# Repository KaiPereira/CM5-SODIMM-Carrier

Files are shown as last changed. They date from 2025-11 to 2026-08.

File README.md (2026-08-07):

# CM5 SO-DIMM Carrier



This SO-DIMM card essentially let's you turn a CM5 into a NVIDIA Jetson card, turing RK1, and other compatible SO-DIMM standards! It's going to be used for my future server cluster motherboard!
## Custom Features!
- Jetson/Turing RK1/Radxa/etc compatible SO-DIMM connector
- Support for SD Card mounting
- GbE Ethernet
- 1x PCIe Gen 3.0
- 2x USB 3.2 Gen 1 support, 1x USB 2.0
- 1x HDMI 2.0
- 2x 4-Lane MIPI CSI
- Misc buttons/LED's

## PCB Design

The CM5 SO-DIMM carrier is a complex 6-layer PCB, with the stackup HIGH-SPEED/GND/SIGNAL/SIGNAL/GND/HIGH-SPEED, with power running along the top layer! You can easily access the [schematic](https://github.com/KaiPereira/CM5-SODIMM-Carrier/blob/master/PCB_CARRIER/SCHEMATIC.pdf), [PCB layers](https://github.com/KaiPereira/CM5-SODIMM-Carrier/blob/master/PCB_CARRIER/PCB.pdf) and [whole PCB](https://github.com/KaiPereira/CM5-SODIMM-Carrier/blob/master/PCB_CARRIER/PCB_WHOLE.pdf) PDF's!







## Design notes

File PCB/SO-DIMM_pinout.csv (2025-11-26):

Pin Name | Name | Direction
USB3-1-TX_N | USB3-1-TX_N | input
CSI-1_D3_P | CSI-1_D3_P | output
HDMI-0_TX2_P | HDMI-0_TX2_P | input
PCIe_CLKREQ | PCIe_CLKREQ | output
CSI-1_CLK_N | CSI-1_CLK_N | input
USB3-0-TX_N | USB3-0-TX_N | input
PCIe_CLK_N | PCIe_CLK_N | input
USB3-0-TX_P | USB3-0-TX_P | input
HDMI-0_CEC | HDMI-0_CEC | bidirectional
HDMI-0_CLK_P | HDMI-0_CLK_P | input
CSI-1_D1_P | CSI-1_D1_P | output
USB3-0-DM | USB3-0-DM | bidirectional
GBE_MDI3_N | GBE_MDI3_N | bidirectional
MOD_SLEEP | MOD_SLEEP | input
PCIe_RX_P | PCIe_RX_P | output
GBE_MDI0_P | GBE_MDI0_P | bidirectional
PCIe_TX_P | PCIe_TX_P | input
CSI-0_CLK_N | CSI-0_CLK_N | input
USB3-0-DP | USB3-0-DP | bidirectional
CSI-1_D2_P | CSI-1_D2_P | output
USB3-1-DM | USB3-1-DM | bidirectional
CSI-1_D0_N | CSI-1_D0_N | output
CSI-0_D2_P | CSI-0_D2_P | output
USB3-1-DP | USB3-1-DP | bidirectional
CSI-0_D0_N | CSI-0_D0_N | output
PCIe_nRST | PCIe_nRST | input
CSI-1_D1_N | CSI-1_D1_N | output
USB_P | USB_P | bidirectional
HDMI-0_TX1_N | HDMI-0_TX1_N | input
POWER_BMC | POWER_BMC | output
USB3-1-RX_P | USB3-1-RX_P | output
CSI-0_D3_P | CSI-0_D3_P | output
CSI-0_SDA | CSI-0_SDA | bidirectional
I2C-0_SCL | I2C-0_SCL | bidirectional
HDMI-0_SDA | HDMI-0_SDA | bidirectional
PCIe_TX_N | PCIe_TX_N | input
CSI-1_CLK_P | CSI-1_CLK_P | input
SHUT_REQ_BMC | SHUT_REQ_BMC | input
HDMI-0_TX0_P | HDMI-0_TX0_P | input
GBE_LED_LINK | GBE_LED_LINK | bidirectional
USB3-1-TX_P | USB3-1-TX_P | input
GBE_LED_ACT | GBE_LED_ACT | bidirectional
PCIe_CLK_P | PCIe_CLK_P | input
HDMI-0_TX2_N | HDMI-0_TX2_N | input
USB3-0-RX_P | USB3-0-RX_P | output
GBE_MDI3_P | GBE_MDI3_P | bidirectional
USB3-1-RX_N | USB3-1-RX_N | output
CSI-0_CLK_P | CSI-0_CLK_P | input
HDMI-0_TX1_P | HDMI-0_TX1_P | input
CSI-0_PWDN | CSI-0_PWDN | output
HDMI-0_SCL | HDMI-0_SCL | bidirectional
CSI-0_D2_N | CSI-0_D2_N | output
USB_N | USB_N | bidirectional
RESET_BMC | RESET_BMC | bidirectional
PCIe_RX_N | PCIe_RX_N | output
GBE_MDI2_N | GBE_MDI2_N | bidirectional
SLEEP/WAKE | SLEEP/WAKE | bidirectional
HDMI-0_TX0_N | HDMI-0_TX0_N | input
USB3-0-RX_N | USB3-0-RX_N | output
CSI-0_D1_P | CSI-0_D1_P | output
CSI-1_PWDN | CSI-1_PWDN | output
CSI-0_D1_N | CSI-0_D1_N | output
GBE_MDI1_N | GBE_MDI1_N | bidirectional
GBE_MDI1_P | GBE_MDI1_P | bidirectional
CSI-0_SCL | CSI-0_SCL | bidirectional
CSI-0_D3_N | CSI-0_D3_N | output
CSI-1_D3_N | CSI-1_D3_N | output
GBE_MDI2_P | GBE_MDI2_P | bidirectional
CSI-1_D0_P | CSI-1_D0_P | output
I2C-0_SDA | I2C-0_SDA | bidirectional
CSI-0_D0_P | CSI-0_D0_P | output
GBE_MDI0_N | GBE_MDI0_N | bidirectional
CSI-1_D2_N | CSI-1_D2_N | output
HDMI-0_HPD | HDMI-0_HPD | input
HDMI-0_CLK_N | HDMI-0_CLK_N | input

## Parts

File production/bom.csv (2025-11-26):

Designator | Footprint | Quantity | Value | LCSC Part #
C1, C10, C14, C15, C17, C19, C2, C3, C4, C5, C6 | 0402 | 11 | 0.1uF
C11, C20 | 0603 | 2 | 10uF
C12, C13, C16, C18, C7, C8, C9 | 0402 | 7 | 1uF
D1 | 0805 | 1 | Green
D2 | 0805 | 1 | Yellow
J1 | SODIMM_DDR4_EDGE | 1 | SODIMM-260_Split
J2 | microSD_HC_Hirose_DM3AT-SF-PEJM5 | 1 | Micro_SD_Card_Det2
MODULE1 | Raspberry-Pi-4-Compute-Module-B | 1 | 10164227-1004A1RLF | 2x DF40C-100DS-0.4V
MODULE2 | Raspberry-Pi-4-Compute-Module-A | 1 | 10164227-1004A1RLF | 2x DF40C-100DS-0.4V
Q2, Q3, Q5 | SOT-23-3 | 3 | BSS138
Q4 | SOT-323_SC-70 | 1 | BC817-40
R1, R15 | 0402 | 2 | 330
R10, R11, R12, R13, R16, R17, R18, R19, R2, R20, R21, R24, R25, R5, R6, R7, R8, R9 | 0402 | 18 | 10K
R14 | 0402 | 1 | 12K
R22, R23, R26, R27, R28, R29, R3, R30, R31, R32, R33, R34, R35, R36, R37, R38, R39, R4, R40, R41, R42, R43, R44, R45, R46, R47, R48, R49, R50, R51, R52, R53, R54, R55, R56, R57, R58, R59, R60, R61 | 0402 | 40 | 0
SW1 | SW_DIP_SPSTx04_Slide_Copal_CHS-04B_W7.62mm_P1.27mm | 1 | SW_DIP_x04
TP1 | TestPoint_Pad_D1.0mm | 1 | RTC Test
TP2 | TestPoint_Pad_D1.0mm | 1 | Sleep Status Output
U1, U2, U3 | TSSOP-24_4.4x5mm_P0.4mm | 3 | SN74LVC8T245
U4 | TSOT-23-5 | 1 | RT9742GGJ5

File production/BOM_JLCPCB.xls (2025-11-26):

JLCPCB BOM Tool - BOM Matching
BOM name：BOM_JLCPCB-JLCPCB Assembly Order.xlsx |  |  | Download Time：2025-11-13 10:06:23 |  |  |  | * Our matching results are updated in real-time, but stock and prices may change. If it's been over 24 hours, please re-match before placing your order.
PCB Assembled Qty：5 |  |  | Est. Total Price：41.7093
Your BOM |  |  |  |  | Matched Parts |  |  |  |  |  |  | Order Information
Top Designator | Bottom Designator | Comment | Footprint | JLCPCB Part # | Matches | Part # | Manufacturer | Footprint | Description | Category | Warning | JLCPCB Part # | Product link | Lib Type | Qty | Source | Total Price ($)
C1,C10,C14,C15,C17,C19,C2,C3,C4,C5,C6 |  | 0.1uF | 0402 |  | Select by System | CL05B104KO5NNNC | Samsung Electro-Mechanics | 0402 | 100nF 16V X7R ±10% 0402 Multilayer Ceramic Capacitors MLCC - SMD/SMT ROHS | Multilayer Ceramic Capacitors MLCC - SMD/SMT |  | C1525 | https://jlcpcb.com/partdetail/1877-CL05B104KO5NNNC/C1525 | Basic | 32 | 32 JLCPCB | 0.0384
C11,C20 |  | 10uF | 0603 |  | Select by System | CL10A106KP8NNNC | Samsung Electro-Mechanics | 0603 | 10V 10uF X5R ±10% 0603 Multilayer Ceramic Capacitors MLCC - SMD/SMT ROHS | Multilayer Ceramic Capacitors MLCC - SMD/SMT |  | C19702 | https://jlcpcb.com/partdetail/20411-CL10A106KP8NNNC/C19702 | Basic | 20 | 20 JLCPCB | 0.112
C12,C13,C16,C18,C7,C8,C9 |  | 1uF | 0402 |  | Select by System | CL05A105KA5NQNC | Samsung Electro-Mechanics | 0402 | 1uF 25V X5R ±10% 0402 Multilayer Ceramic Capacitors MLCC - SMD/SMT ROHS | Multilayer Ceramic Capacitors MLCC - SMD/SMT |  | C52923 | https://jlcpcb.com/partdetail/53938-CL05A105KA5NQNC/C52923 | Basic | 24 | 24 JLCPCB | 0.0696
D1 |  | Green | 0805 |  | Select by System | KT-0805G | Hubei KENTO Elec | 0805 | -40℃~+85℃ 100mW 120° 2.6V~3.1V 430mcd 513nm~528nm 525nm 5mA Emerald Green 0805 LED Indication - Discrete ROHS | LED Indication - Discrete |  | C2297 | https://jlcpcb.com/partdetail/Hubei_KENTOElec-KT0805G/C2297 | Basic | 20 | 20 JLCPCB | 0.216
D2 |  | Yellow | 0805 |  | Select by System | KT-0805Y | Hubei KENTO Elec | 0805 | -40℃~+85℃ 1.8V~2.4V 120° 175mcd 40mW 584nm~594nm 596nm Water Clear Yellow 0805 LED Indication - Discrete ROHS | LED Indication - Discrete |  | C2296 | https://jlcpcb.com/partdetail/Hubei_KENTOElec-KT0805Y/C2296 | Basic | 20 | 20 JLCPCB | 0.27
J2 |  | Micro_SD_Card_Det2 | SMD |  | Select by System | DM3AT-SF-PEJM5 | HRS(Hirose) | SMD | -25℃~+85℃ 1.68mm Connector and Ejector MicroSD Card (TF Card) No Push-Push SMD SD Card / Memory Card Connector ROHS | SD Card / Memory Card Connector |  | C114218 | https://jlcpcb.com/partdetail/HRS_Hirose-DM3AT_SFPEJM5/C114218 | Extended | 2 | 2 JLCPCB | 2.562
MODULE1 |  | Mezzanine_B | SMD,P=0.4mm |  | Unconfirmed | 10164227-1004A1RLF | Amphenol ICC | SMD,P=0.4mm | SMD,P=0.4mm Board-to-Board and Backplane Connector ROHS | Global Sourcing Parts | 1.Multiple lines in the BOM have been matched to the same part. Please check if the matching is correct. ; | C7435219 | https://jlcpcb.com/partdetail/AmphenolICC-101642271004A1RLF/C7435219 | Extended | 4 | 4 JLCPCB | 14.592
MODULE2 |  | Mezzanine_A | SMD,P=0.4mm |  | Unconfirmed | 10164227-1004A1RLF | Amphenol ICC | SMD,P=0.4mm | SMD,P=0.4mm Board-to-Board and Backplane Connector ROHS | Global Sourcing Parts | 1.Multiple lines in the BOM have been matched to the same part. Please check if the matching is correct. ; | C7435219 | https://jlcpcb.com/partdetail/AmphenolICC-101642271004A1RLF/C7435219 | Extended | 4 | 4 JLCPCB | 14.592
Q2,Q3,Q5 |  | BSS138 | SOT-23 |  | Select by System | BSS138 | hongjiacheng | SOT-23 | -55℃~+150℃ 1 N-Channel 1.1Ω@10V 1.2V@250uA 1.7nC@10V 17.5pF@25V 340mA 350mW 50V 6.5pF@25V N-Channel SOT-23 MOSFETs ROHS | MOSFETs |  | C7420339 | https://jlcpcb.com/partdetail/hongjiacheng-BSS138/C7420339 | Extended | 11 | 11 JLCPCB | 0.1782
Q4 |  | BC817-40 | SOT-23 |  | Select by System | BC817-40 | hongjiacheng | SOT-23 | -55℃~+150℃ 100@100mA,1.0V 100MHz 100nA 300mW 45V 500mA 5V 700mV@500mA,50mA NPN SOT-23 Bipolar (BJT) ROHS | Bipolar (BJT) |  | C20069155 | https://jlcpcb.com/partdetail/hongjiacheng-BC81740/C20069155 | Extended | 10 | 10 JLCPCB | 0.179
R1,R15 |  | 330 | 0402 |  | Select by System | 0402WGF3300TCE | UNI-ROYAL(Uniroyal Elec) | 0402 | -55℃~+155℃ 330Ω 50V 62.5mW Thick Film Resistor ±1% ±100ppm/℃ 0402 Chip Resistor - Surface Mount ROHS | Chip Resistor - Surface Mount |  | C25104 | https://jlcpcb.com/partdetail/25847-0402WGF3300TCE/C25104 | Basic | 20 | 20 JLCPCB | 0.014
R10,R11,R12,R13,R16,R17,R18,R19,R2,R20,R21,R24,R25,R5,R6,R7,R8,R9 |  | 10K | 0402 |  | Select by System | 0402WGF1002TCE | UNI-ROYAL(Uniroyal Elec) | 0402 | -55℃~+155℃ 10kΩ 50V 62.5mW Thick Film Resistor ±1% ±100ppm/℃ 0402 Chip Resistor - Surface Mount ROHS | Chip Resistor - Surface Mount |  | C25744 | https://jlcpcb.com/partdetail/26487-0402WGF1002TCE/C25744 | Basic | 46 | 46 JLCPCB | 0.0276
R14 |  | 12K | 0402 |  | Select by System | 0402WGF1202TCE | UNI-ROYAL(Uniroyal Elec) | 0402 | -55℃~+155℃ 12kΩ 50V 62.5mW Thick Film Resistor ±1% ±100ppm/℃ 0402 Chip Resistor - Surface Mount ROHS | Chip Resistor - Surface Mount |  | C25752 | https://jlcpcb.com/partdetail/26495-0402WGF1202TCE/C25752 | Basic | 20 | 20 JLCPCB | 0.012
R22,R23,R26,R27,R28,R29,R3,R30,R31,R32,R33,R34,R35,R36,R37,R38,R39,R4,R40,R41,R42,R43,R44,R45,R46,R47,R48,R49,R50,R51,R52,R53,R54,R55,R56,R57,R58,R59,R60,R61 |  | 0 | 0402 |  | Select by System | 0402WGF0000TCE | UNI-ROYAL(Uniroyal Elec) | 0402 | -55℃~+155℃ 0Ω 50V 62.5mW Thick Film Resistor ±1% ±800ppm/℃ 0402 Chip Resistor - Surface Mount ROHS | Chip Resistor - Surface Mount |  | C17168 | https://jlcpcb.com/partdetail/17853-0402WGF0000TCE/C17168 | Basic | 90 | 90 JLCPCB | 0.045
SW1 |  | SW_DIP_x04 |  |  | Select by Customer | DSHP04TSGET | DongGuan KINGTEK Industrial Co.,LTD | SMD,P=1.27mm | 1.27mm 4 Black SPST Slide, Recessed SMD,P=1.27mm DIP Switches ROHS | DIP Switches |  | C40736 | https://jlcpcb.com/partdetail/41720-DSHP04TSGET/C40736 | Extended | 2 | 2 JLCPCB | 0.939
U1,U2,U3 |  | SN74LVC8T245 | TSSOP-24 |  | Select by Customer | SN74LVCH8T245DGVR | Texas Instruments | TVSOP-20 | -40℃~+85℃ 1.65V~5.5V 1.65V~5.5V Bidirectional Power-Off Protection Tri-State TVSOP-20 Translators, Level Shifters ROHS | Translators, Level Shifters |  | C2873141 | https://jlcpcb.com/partdetail/TexasInstruments-SN74LVCH8T245DGVR/C2873141 | Extended | 6 | 6 JLCPCB | 7.182
U4 |  | RT9742GGJ5 | TSOT-23-5 |  | Select by System | RT9742GGJ5 | Richtek Tech | TSOT-23-5 | -40℃~+85℃ 1 1A 2.7V~6V 70mΩ Active High High Side Switch Short-Circuit Protection(SCP) TSOT-23-5 Power Distribution Switches ROHS | Power Distribution Switches |  | C250547 | https://jlcpcb.com/partdetail/RichtekTech-RT9742GGJ5/C250547 | Extended | 5 | 5 JLCPCB | 0.6805
J1 |  | SODIMM-260_Split |  |  | No matches | No Part Selected

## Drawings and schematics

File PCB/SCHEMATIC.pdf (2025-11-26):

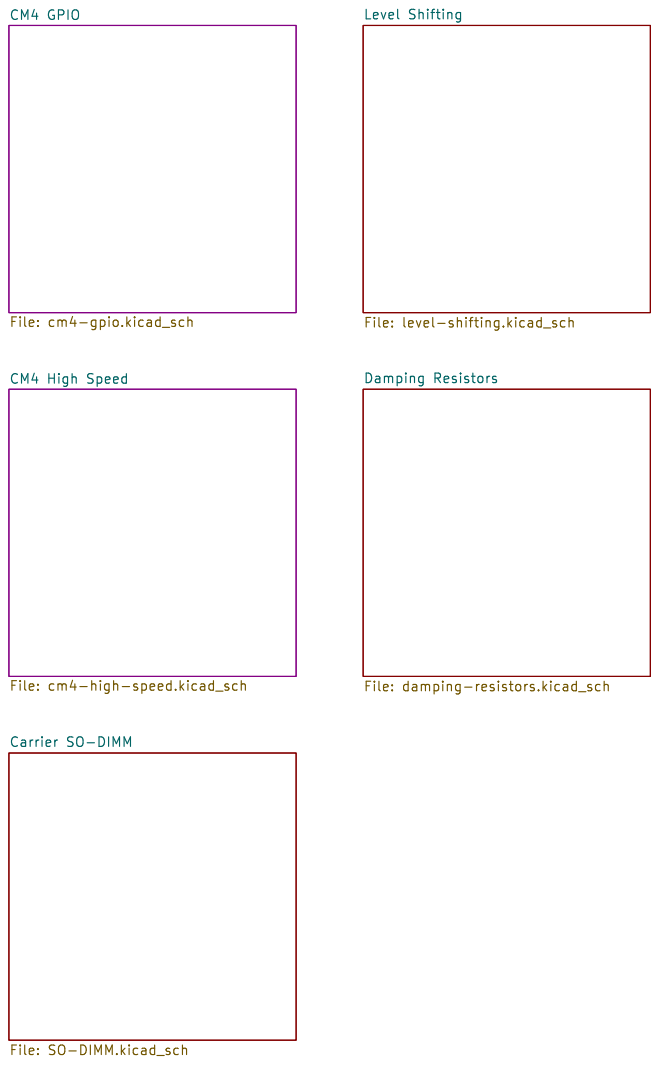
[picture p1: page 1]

Level Shifting File: level-shifting.kicad_sch Carrier SO-DIMM
CM4 GPIO

CM4 High Speed File: cm4-high-speed.kicad_sch

Damping Resistors File: damping-resistors.kicad_sch

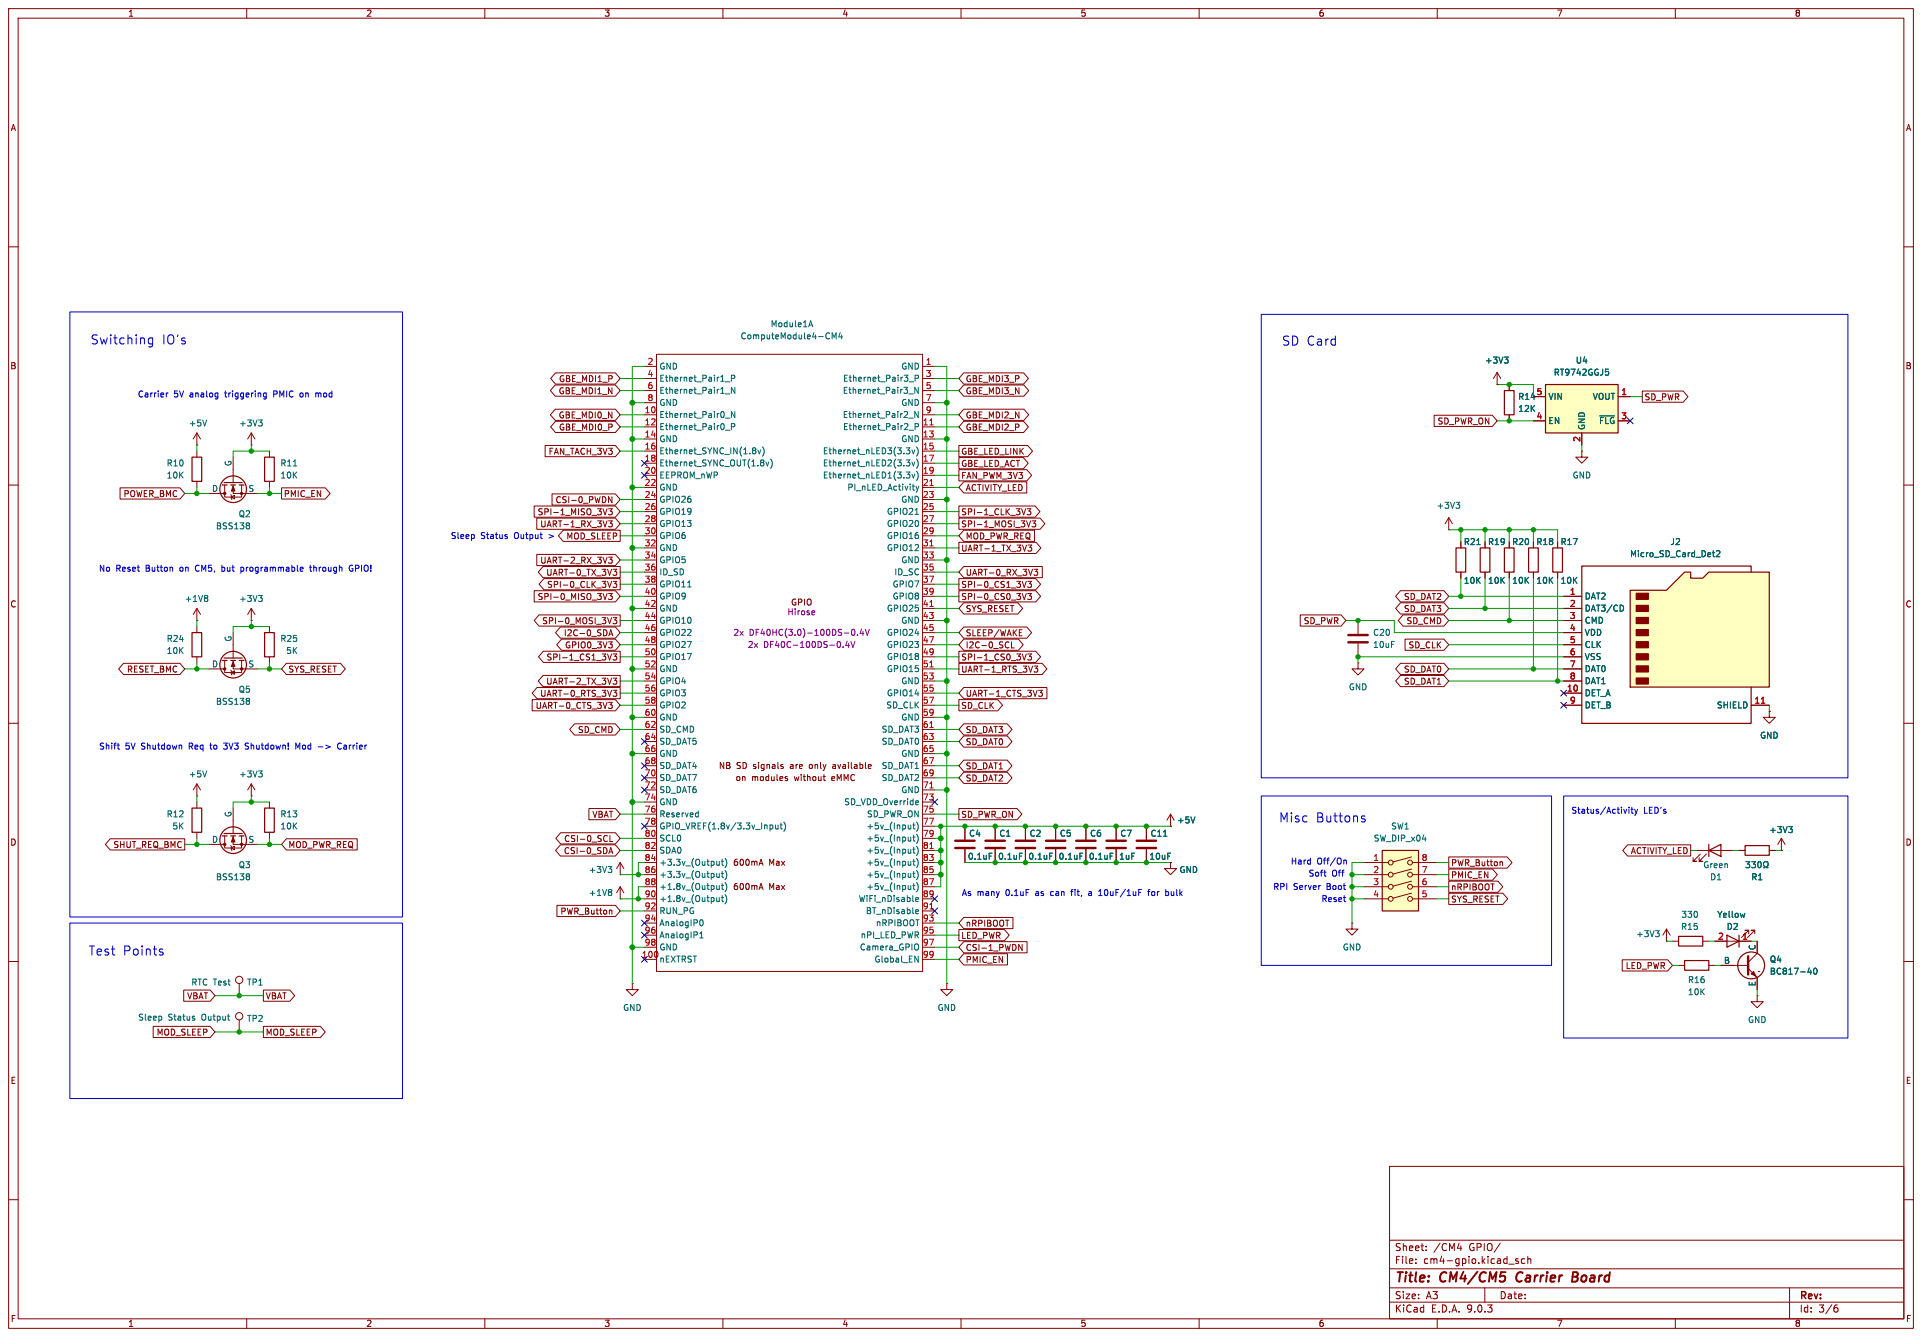
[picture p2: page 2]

UART-0_CTS_3V3 UART-2_TX_3V3 Switching IO's

SPI-0_CS1_3V3 GBE_MDI3_N MOD_PWR_REQ
FAN_PWM_3V3 SPI-1_CLK_3V3 SYS_RESET SPI-0_CS0_3V3 SLEEP/WAKE GBE_MDI2_N

SD_DAT2 PMIC_EN
SPI-1_MISO_3V3 SPI-0_CLK_3V3 UART-2_RX_3V3 SPI-0_MISO_3V3 VBAT

on modules without eMMC GPIO

600mA Max 600mA Max NB SD signals are only available

Hard Off/On Misc Buttons

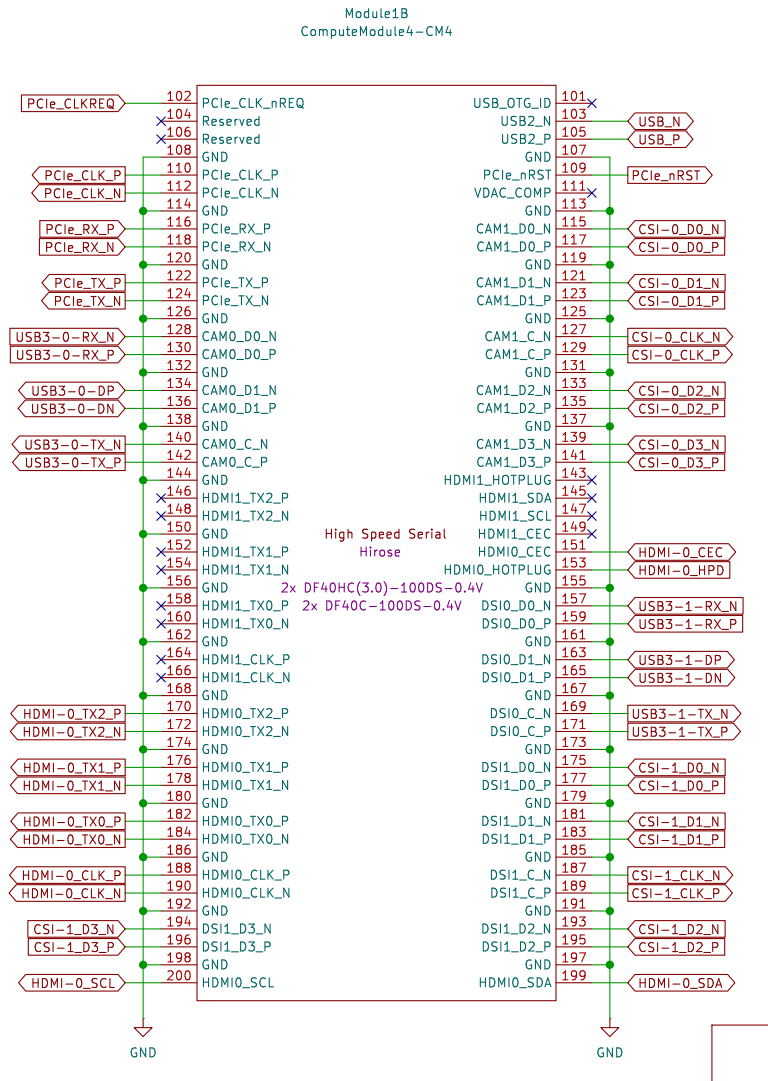
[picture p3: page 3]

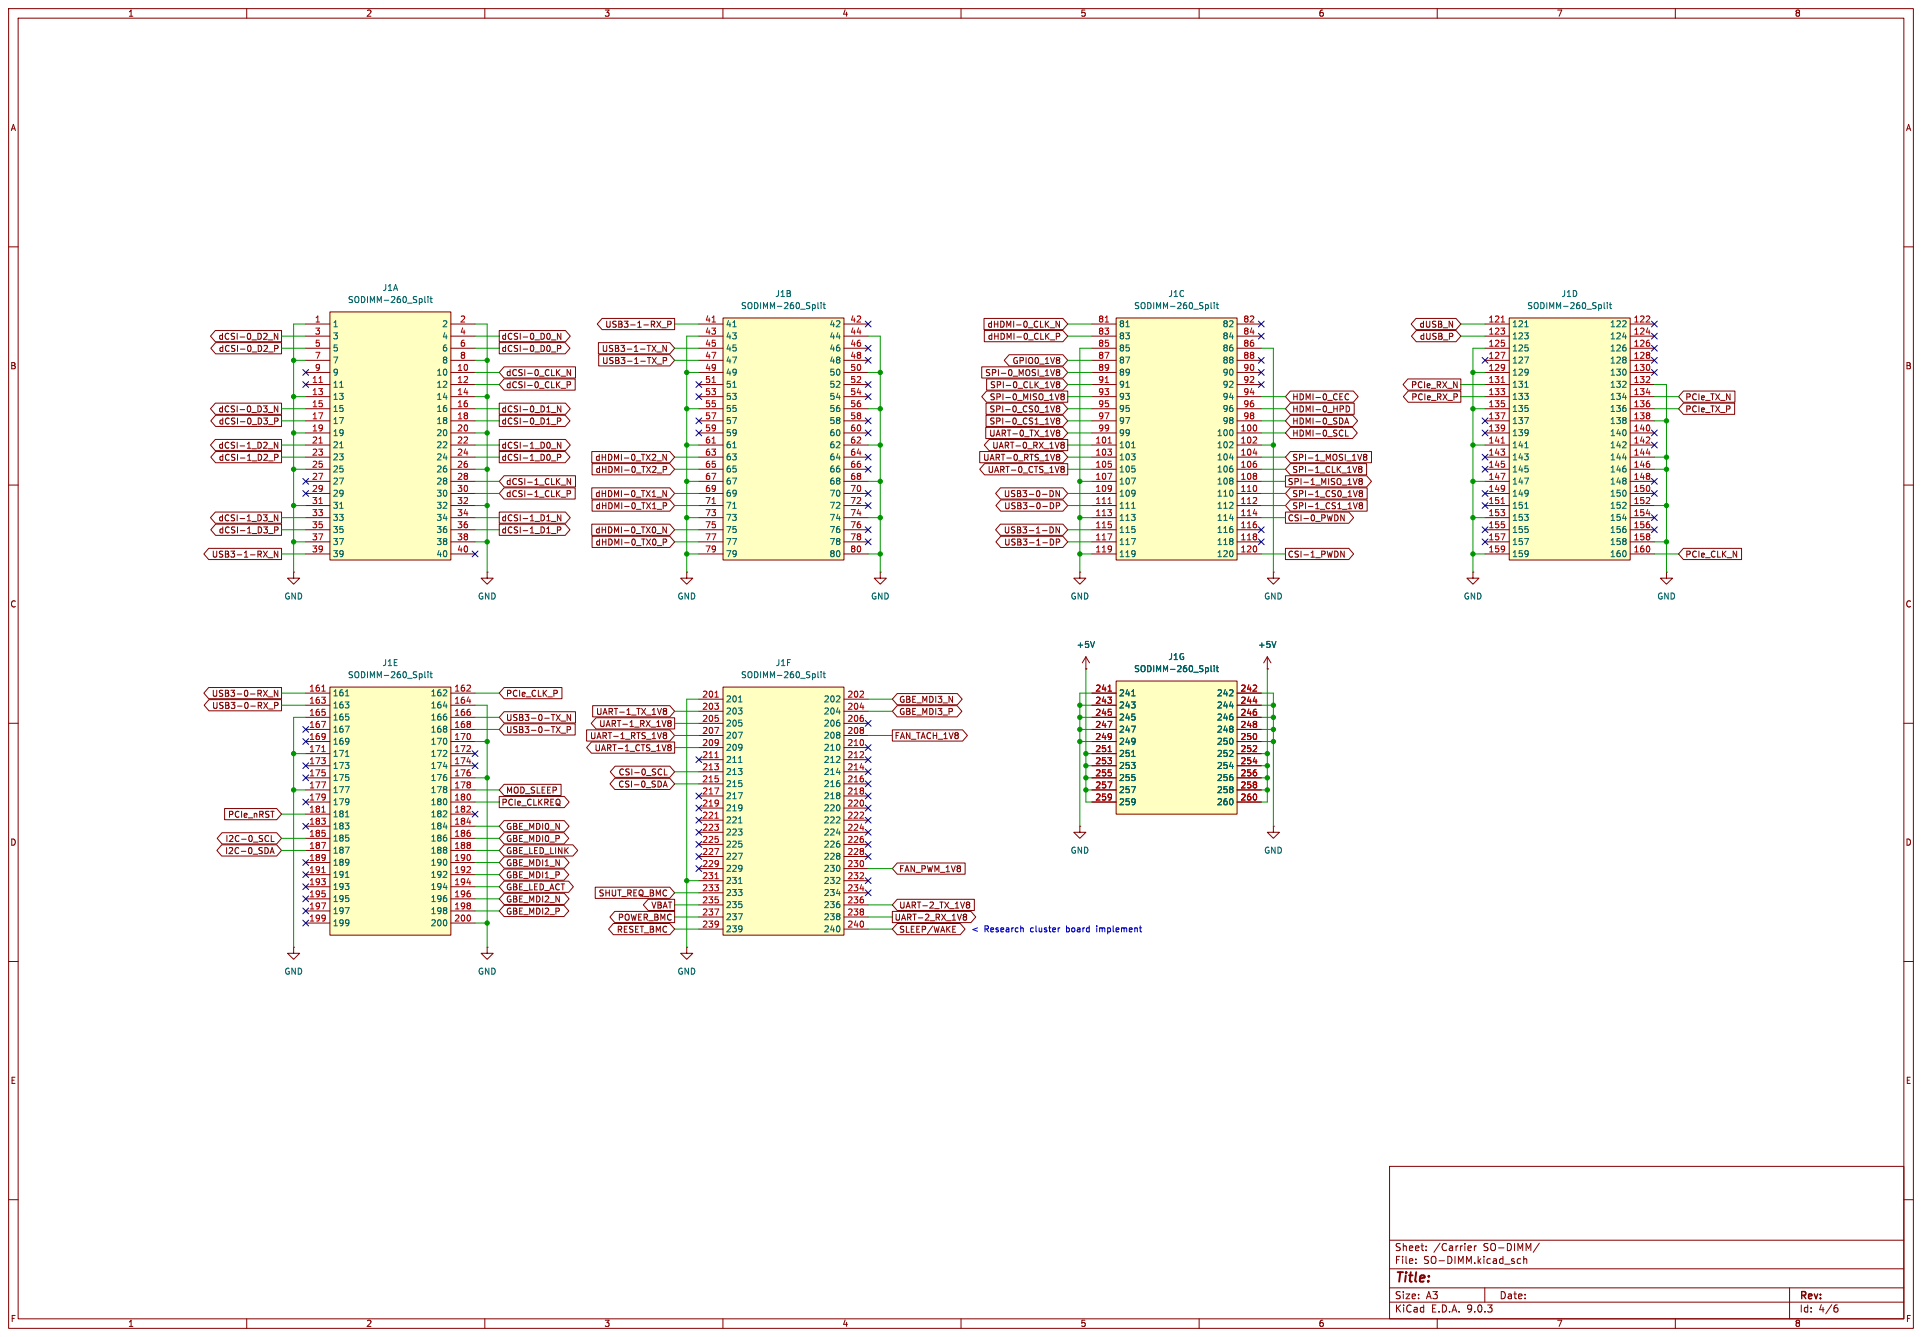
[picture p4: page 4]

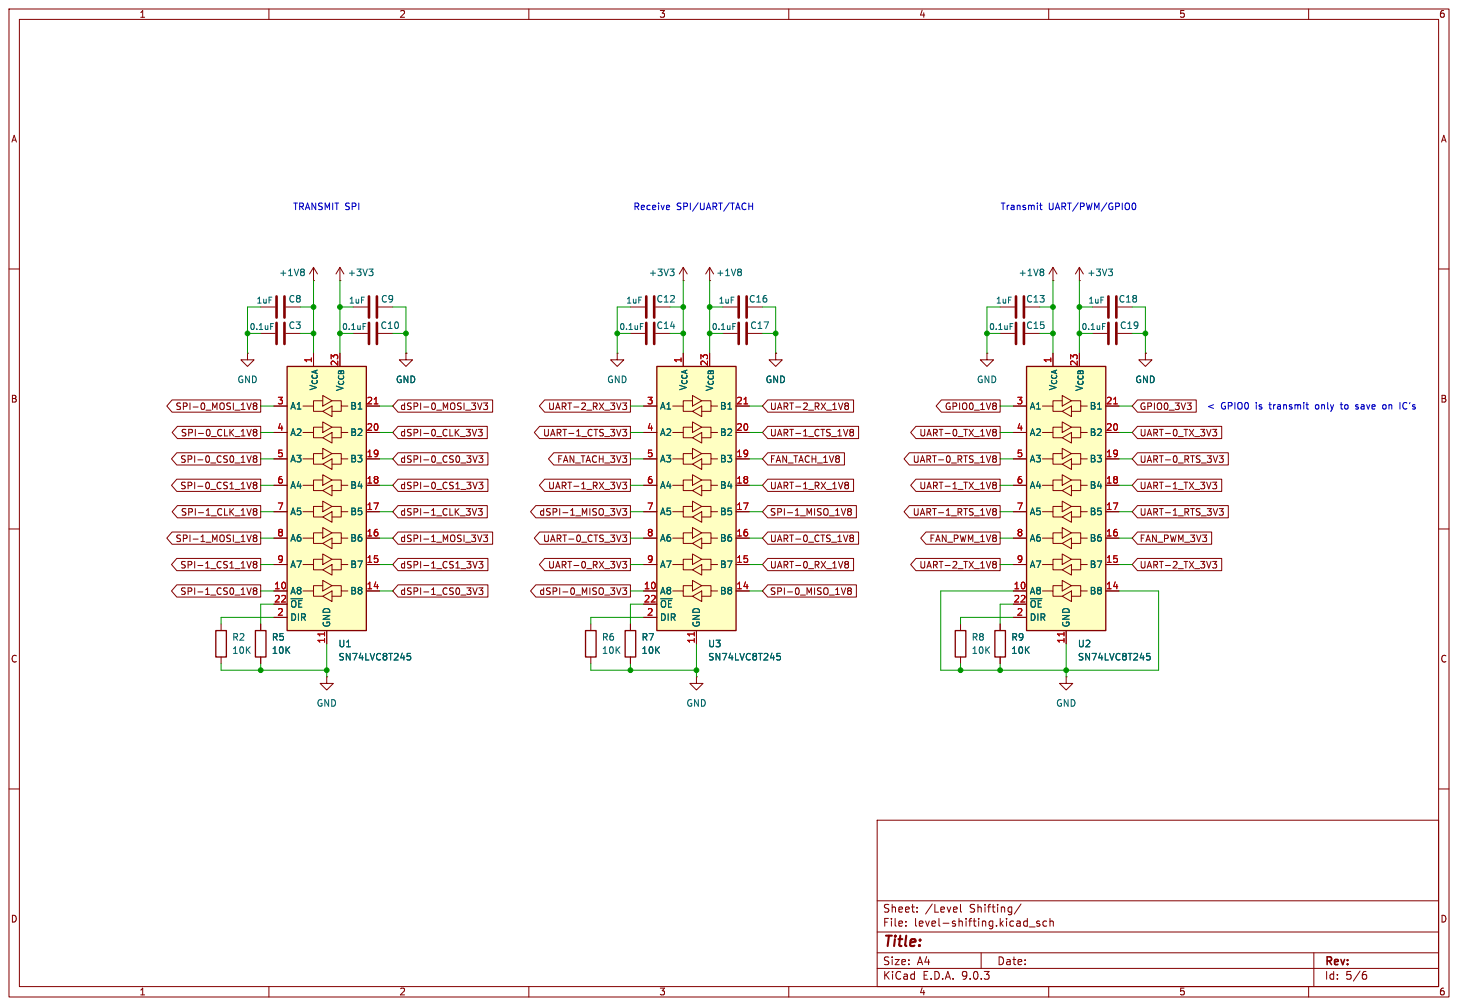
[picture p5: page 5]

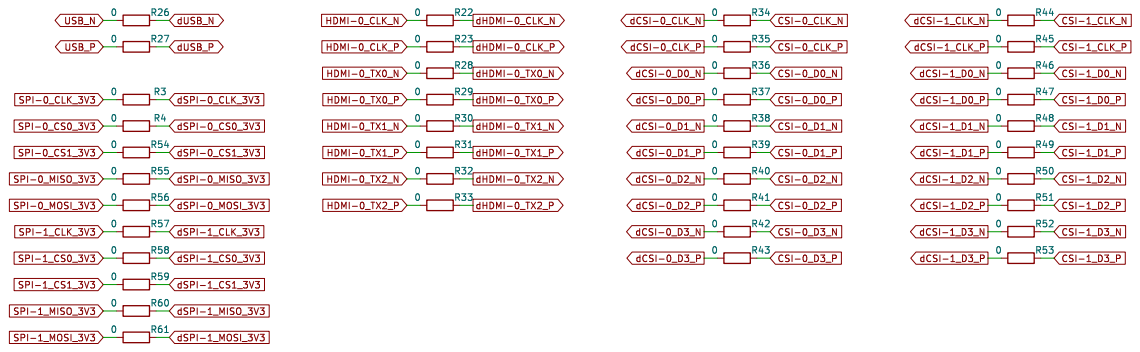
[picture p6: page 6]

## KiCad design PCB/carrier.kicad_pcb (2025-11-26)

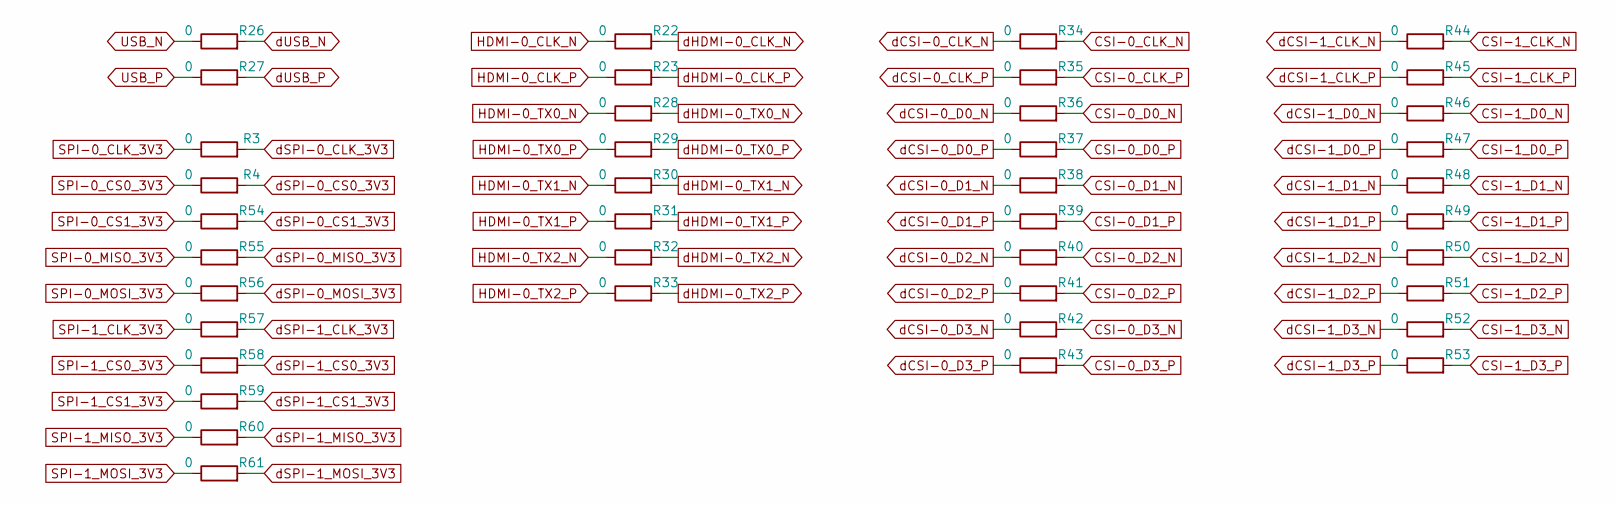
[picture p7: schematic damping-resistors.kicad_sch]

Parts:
R3, R4, R22, R23, R26, R27, R28, R29, R30, R31, R32, R33, R34, R35, R36, R37, R38, R39, R40, R41, R42, R43, R44, R45, R46, R47, R48, R49, R50, R51, R52, R53, R54, R55, R56, R57, R58, R59, R60, R61: 0; R_0402_1005Metric

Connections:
CSI-0_CLK_N: R34.2; also elsewhere on the board
CSI-0_CLK_P: R35.2; also elsewhere on the board
CSI-0_D0_N: R36.2; also elsewhere on the board
CSI-0_D0_P: R37.2; also elsewhere on the board
CSI-0_D1_N: R38.2; also elsewhere on the board
CSI-0_D1_P: R39.2; also elsewhere on the board
CSI-0_D2_N: R40.2; also elsewhere on the board
CSI-0_D2_P: R41.2; also elsewhere on the board
CSI-0_D3_N: R42.2; also elsewhere on the board
CSI-0_D3_P: R43.2; also elsewhere on the board
CSI-1_CLK_N: R44.2; also elsewhere on the board
CSI-1_CLK_P: R45.2; also elsewhere on the board
CSI-1_D0_N: R46.2; also elsewhere on the board
CSI-1_D0_P: R47.2; also elsewhere on the board
CSI-1_D1_N: R48.2; also elsewhere on the board
CSI-1_D1_P: R49.2; also elsewhere on the board
CSI-1_D2_N: R50.2; also elsewhere on the board
CSI-1_D2_P: R51.2; also elsewhere on the board
CSI-1_D3_N: R52.2; also elsewhere on the board
CSI-1_D3_P: R53.2; also elsewhere on the board
HDMI-0_CLK_N: R22.1; also elsewhere on the board
HDMI-0_CLK_P: R23.1; also elsewhere on the board
HDMI-0_TX0_N: R28.1; also elsewhere on the board
HDMI-0_TX0_P: R29.1; also elsewhere on the board
HDMI-0_TX1_N: R30.1; also elsewhere on the board
HDMI-0_TX1_P: R31.1; also elsewhere on the board
HDMI-0_TX2_N: R32.1; also elsewhere on the board
HDMI-0_TX2_P: R33.1; also elsewhere on the board
SPI-0_CLK_3V3: R3.1; also elsewhere on the board
SPI-0_CS0_3V3: R4.1; also elsewhere on the board
SPI-0_CS1_3V3: R54.1; also elsewhere on the board
SPI-0_MISO_3V3: R55.1; also elsewhere on the board
SPI-0_MOSI_3V3: R56.1; also elsewhere on the board
SPI-1_CLK_3V3: R57.1; also elsewhere on the board
SPI-1_CS0_3V3: R58.1; also elsewhere on the board
SPI-1_CS1_3V3: R59.1; also elsewhere on the board
SPI-1_MISO_3V3: R60.1; also elsewhere on the board
SPI-1_MOSI_3V3: R61.1; also elsewhere on the board
USB_N: R26.1; also elsewhere on the board
USB_P: R27.1; also elsewhere on the board
dCSI-0_CLK_N: R34.1; also elsewhere on the board
dCSI-0_CLK_P: R35.1; also elsewhere on the board
dCSI-0_D0_N: R36.1; also elsewhere on the board
dCSI-0_D0_P: R37.1; also elsewhere on the board
dCSI-0_D1_N: R38.1; also elsewhere on the board
dCSI-0_D1_P: R39.1; also elsewhere on the board
dCSI-0_D2_N: R40.1; also elsewhere on the board
dCSI-0_D2_P: R41.1; also elsewhere on the board
dCSI-0_D3_N: R42.1; also elsewhere on the board
dCSI-0_D3_P: R43.1; also elsewhere on the board
dCSI-1_CLK_N: R44.1; also elsewhere on the board
dCSI-1_CLK_P: R45.1; also elsewhere on the board
dCSI-1_D0_N: R46.1; also elsewhere on the board
dCSI-1_D0_P: R47.1; also elsewhere on the board
dCSI-1_D1_N: R48.1; also elsewhere on the board
dCSI-1_D1_P: R49.1; also elsewhere on the board
dCSI-1_D2_N: R50.1; also elsewhere on the board
dCSI-1_D2_P: R51.1; also elsewhere on the board
dCSI-1_D3_N: R52.1; also elsewhere on the board
dCSI-1_D3_P: R53.1; also elsewhere on the board
dHDMI-0_CLK_N: R22.2; also elsewhere on the board
dHDMI-0_CLK_P: R23.2; also elsewhere on the board
dHDMI-0_TX0_N: R28.2; also elsewhere on the board
dHDMI-0_TX0_P: R29.2; also elsewhere on the board
dHDMI-0_TX1_N: R30.2; also elsewhere on the board
dHDMI-0_TX1_P: R31.2; also elsewhere on the board
dHDMI-0_TX2_N: R32.2; also elsewhere on the board
dHDMI-0_TX2_P: R33.2; also elsewhere on the board
dSPI-0_CLK_3V3: R3.2; also elsewhere on the board
dSPI-0_CS0_3V3: R4.2; also elsewhere on the board
dSPI-0_CS1_3V3: R54.2; also elsewhere on the board
dSPI-0_MISO_3V3: R55.2; also elsewhere on the board
dSPI-0_MOSI_3V3: R56.2; also elsewhere on the board
dSPI-1_CLK_3V3: R57.2; also elsewhere on the board
dSPI-1_CS0_3V3: R58.2; also elsewhere on the board
dSPI-1_CS1_3V3: R59.2; also elsewhere on the board
dSPI-1_MISO_3V3: R60.2; also elsewhere on the board
dSPI-1_MOSI_3V3: R61.2; also elsewhere on the board
dUSB_N: R26.2; also elsewhere on the board
dUSB_P: R27.2; also elsewhere on the board

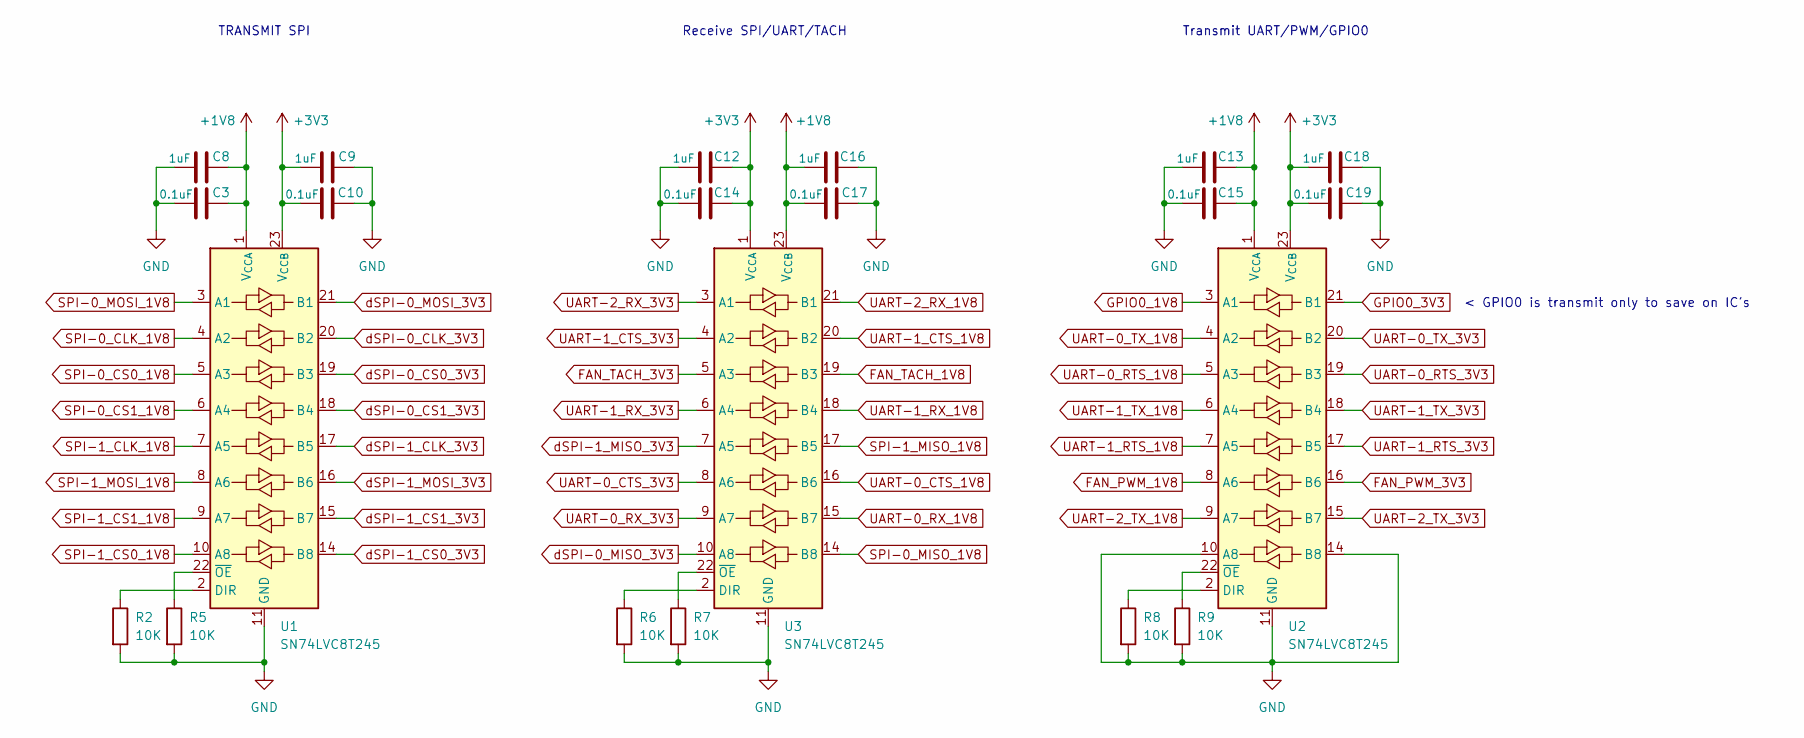
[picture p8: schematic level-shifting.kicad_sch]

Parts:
C3, C10, C14, C15, C17, C19: 0.1uF; C_0402_1005Metric
C8, C9, C12, C13, C16, C18: 1uF; C_0402_1005Metric
R2, R5, R6, R7, R8, R9: 10K; R_0402_1005Metric
U1, U2, U3: SN74LVC8T245; TSSOP-24_4.4x5mm_P0.4mm

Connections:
+1V8: C3.2, C8.2, C13.2, C15.2, C16.1, C17.1, U1.1 (V_{CCA}), U2.1 (V_{CCA}), U3.23 (V_{CCB}), U3.24 (V_{CCB}); also elsewhere on the board
+3V3: C9.1, C10.1, C12.2, C14.2, C18.1, C19.1, U1.23 (V_{CCB}), U1.24 (V_{CCB}), U2.23 (V_{CCB}), U2.24 (V_{CCB}), U3.1 (V_{CCA}); also elsewhere on the board
FAN_PWM_1V8: U2.8 (A6); also elsewhere on the board
FAN_PWM_3V3: U2.16 (B6); also elsewhere on the board
FAN_TACH_1V8: U3.19 (B3); also elsewhere on the board
FAN_TACH_3V3: U3.5 (A3); also elsewhere on the board
GND: C3.1, C8.1, C9.2, C10.2, C12.1, C13.1, C14.1, C15.1, C16.2, C17.2, C18.2, C19.2, R2.2, R5.2, R6.2, R7.2, R8.2, R9.2, U1.11 (GND), U1.12 (GND), U1.13 (GND), U2.10 (A8), U2.11 (GND), U2.12 (GND), U2.13 (GND), U2.14 (B8), U3.11 (GND), U3.12 (GND), U3.13 (GND); also elsewhere on the board
GPIO0_1V8: U2.3 (A1); also elsewhere on the board
GPIO0_3V3: U2.21 (B1); also elsewhere on the board
unnamed: R2.1, U1.2 (DIR)
unnamed: R5.1, U1.22 (~OE)
unnamed: R8.1, U2.2 (DIR)
unnamed: R9.1, U2.22 (~OE)
unnamed: R6.1, U3.2 (DIR)
unnamed: R7.1, U3.22 (~OE)
SPI-0_CLK_1V8: U1.4 (A2); also elsewhere on the board
SPI-0_CS0_1V8: U1.5 (A3); also elsewhere on the board
SPI-0_CS1_1V8: U1.6 (A4); also elsewhere on the board
SPI-0_MISO_1V8: U3.14 (B8); also elsewhere on the board
SPI-0_MOSI_1V8: U1.3 (A1); also elsewhere on the board
SPI-1_CLK_1V8: U1.7 (A5); also elsewhere on the board
SPI-1_CS0_1V8: U1.10 (A8); also elsewhere on the board
SPI-1_CS1_1V8: U1.9 (A7); also elsewhere on the board
SPI-1_MISO_1V8: U3.17 (B5); also elsewhere on the board
SPI-1_MOSI_1V8: U1.8 (A6); also elsewhere on the board
UART-0_CTS_1V8: U3.16 (B6); also elsewhere on the board
UART-0_CTS_3V3: U3.8 (A6); also elsewhere on the board
UART-0_RTS_1V8: U2.5 (A3); also elsewhere on the board
UART-0_RTS_3V3: U2.19 (B3); also elsewhere on the board
UART-0_RX_1V8: U3.15 (B7); also elsewhere on the board
UART-0_RX_3V3: U3.9 (A7); also elsewhere on the board
UART-0_TX_1V8: U2.4 (A2); also elsewhere on the board
UART-0_TX_3V3: U2.20 (B2); also elsewhere on the board
UART-1_CTS_1V8: U3.20 (B2); also elsewhere on the board
UART-1_CTS_3V3: U3.4 (A2); also elsewhere on the board
UART-1_RTS_1V8: U2.7 (A5); also elsewhere on the board
UART-1_RTS_3V3: U2.17 (B5); also elsewhere on the board
UART-1_RX_1V8: U3.18 (B4); also elsewhere on the board
UART-1_RX_3V3: U3.6 (A4); also elsewhere on the board
UART-1_TX_1V8: U2.6 (A4); also elsewhere on the board
UART-1_TX_3V3: U2.18 (B4); also elsewhere on the board
UART-2_RX_1V8: U3.21 (B1); also elsewhere on the board
UART-2_RX_3V3: U3.3 (A1); also elsewhere on the board
UART-2_TX_1V8: U2.9 (A7); also elsewhere on the board
UART-2_TX_3V3: U2.15 (B7); also elsewhere on the board
dSPI-0_CLK_3V3: U1.20 (B2); also elsewhere on the board
dSPI-0_CS0_3V3: U1.19 (B3); also elsewhere on the board
dSPI-0_CS1_3V3: U1.18 (B4); also elsewhere on the board
dSPI-0_MISO_3V3: U3.10 (A8); also elsewhere on the board
dSPI-0_MOSI_3V3: U1.21 (B1); also elsewhere on the board
dSPI-1_CLK_3V3: U1.17 (B5); also elsewhere on the board
dSPI-1_CS0_3V3: U1.14 (B8); also elsewhere on the board
dSPI-1_CS1_3V3: U1.15 (B7); also elsewhere on the board
dSPI-1_MISO_3V3: U3.7 (A5); also elsewhere on the board
dSPI-1_MOSI_3V3: U1.16 (B6); also elsewhere on the board

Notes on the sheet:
TRANSMIT SPI
Receive SPI/UART/TACH
Transmit UART/PWM/GPIO0
< GPIO0 is transmit only to save on IC's

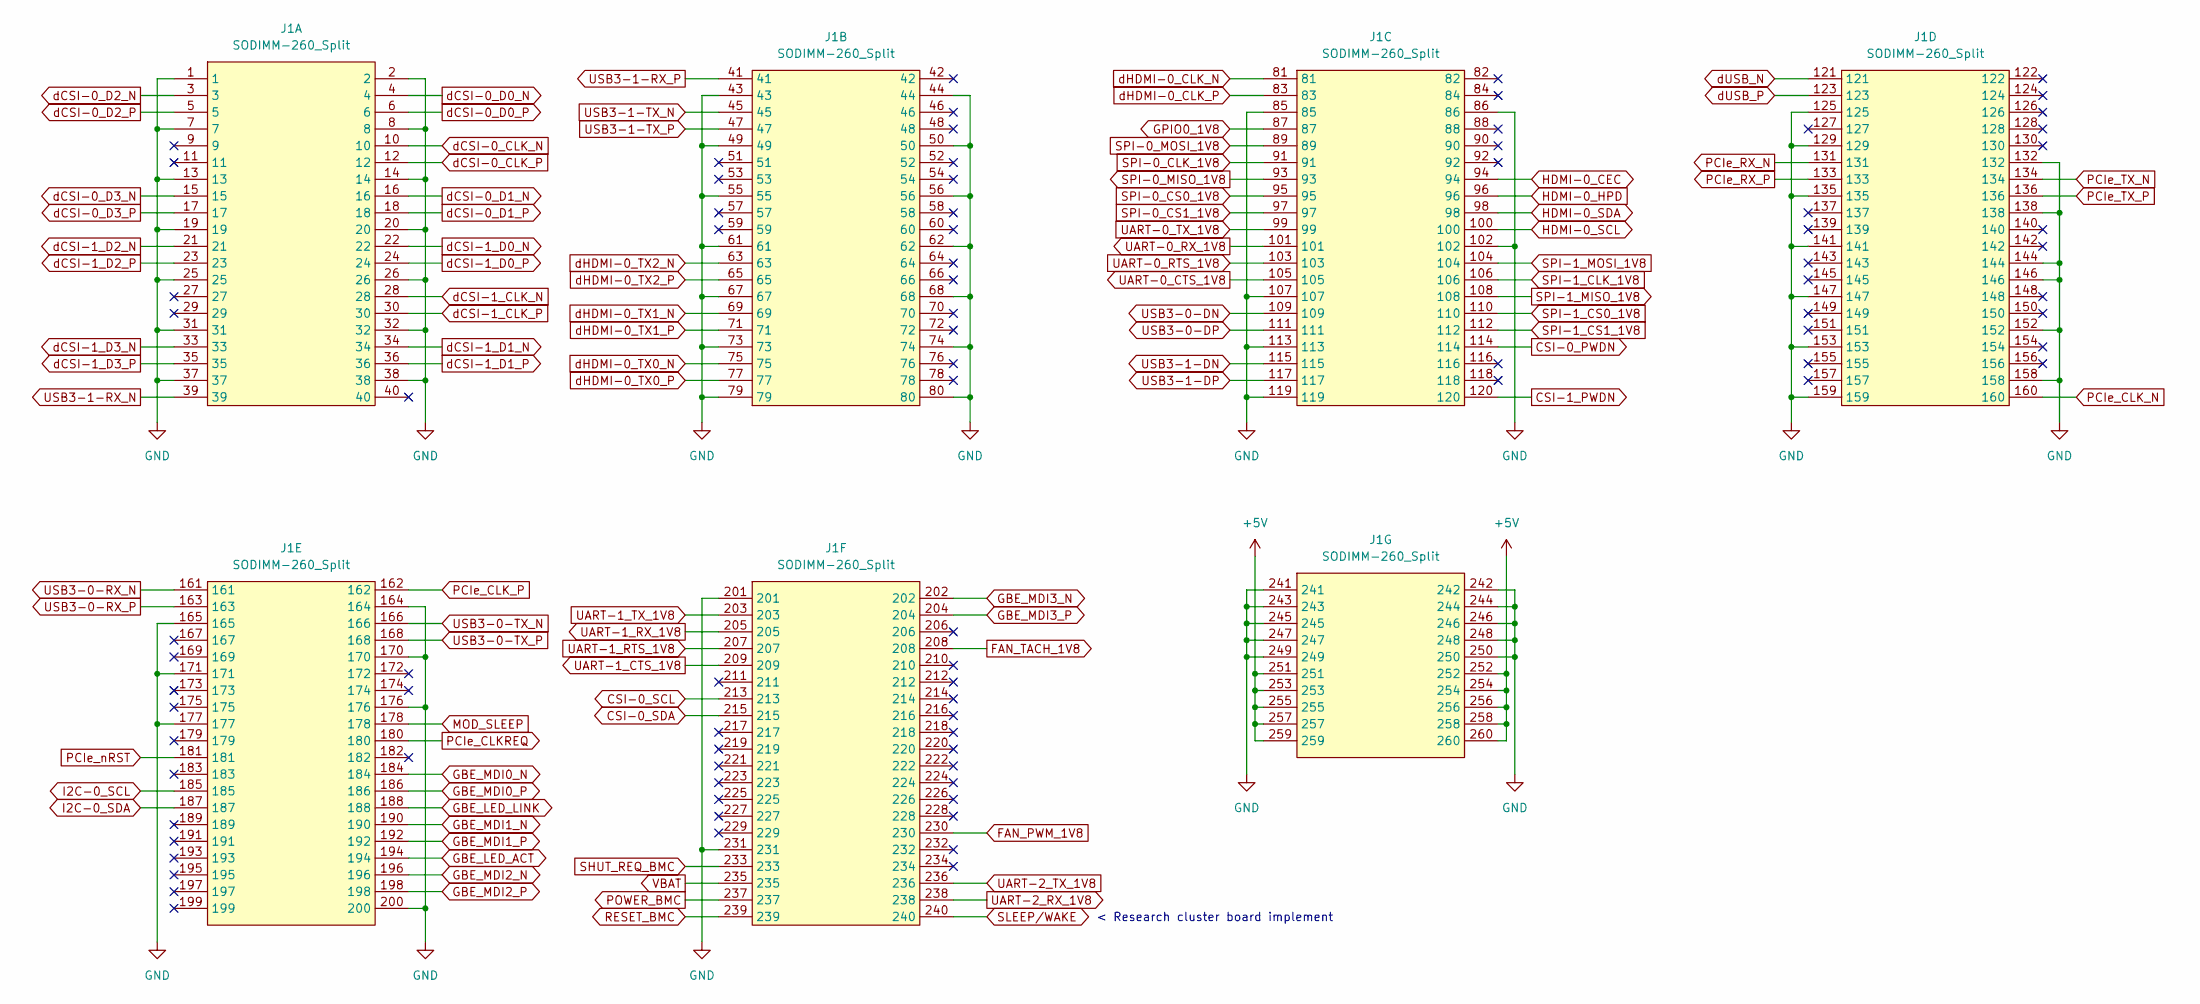
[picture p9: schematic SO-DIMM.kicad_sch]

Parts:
J1: SODIMM-260_Split; SODIMM_DDR4_EDGE

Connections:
+5V: J1.251, J1.252, J1.253, J1.254, J1.255, J1.256, J1.257, J1.258, J1.259, J1.260; also elsewhere on the board
CSI-0_PWDN: J1.114; also elsewhere on the board
CSI-0_SCL: J1.213; also elsewhere on the board
CSI-0_SDA: J1.215; also elsewhere on the board
CSI-1_PWDN: J1.120; also elsewhere on the board
FAN_PWM_1V8: J1.230; also elsewhere on the board
FAN_TACH_1V8: J1.208; also elsewhere on the board
GBE_LED_ACT: J1.194; also elsewhere on the board
GBE_LED_LINK: J1.188; also elsewhere on the board
GBE_MDI0_N: J1.184; also elsewhere on the board
GBE_MDI0_P: J1.186; also elsewhere on the board
GBE_MDI1_N: J1.190; also elsewhere on the board
GBE_MDI1_P: J1.192; also elsewhere on the board
GBE_MDI2_N: J1.196; also elsewhere on the board
GBE_MDI2_P: J1.198; also elsewhere on the board
GBE_MDI3_N: J1.202; also elsewhere on the board
GBE_MDI3_P: J1.204; also elsewhere on the board
GND: J1.1, J1.2, J1.7, J1.8, J1.13, J1.14, J1.19, J1.20, J1.25, J1.26, J1.31, J1.32, J1.37, J1.38, J1.43, J1.44, J1.49, J1.50, J1.55, J1.56, J1.61, J1.62, J1.67, J1.68, J1.73, J1.74, J1.79, J1.80, J1.85, J1.86, J1.102, J1.107, J1.113, J1.119, J1.125, J1.129, J1.132, J1.135, J1.138, J1.141, J1.144, J1.146, J1.147, J1.152, J1.153, J1.158, J1.159, J1.164, J1.165, J1.170, J1.171, J1.176, J1.177, J1.200, J1.201, J1.231, J1.241, J1.242, J1.243, J1.244, J1.245, J1.246, J1.247, J1.248, J1.249, J1.250; also elsewhere on the board
GPIO0_1V8: J1.87; also elsewhere on the board
HDMI-0_CEC: J1.94; also elsewhere on the board
HDMI-0_HPD: J1.96; also elsewhere on the board
HDMI-0_SCL: J1.100; also elsewhere on the board
HDMI-0_SDA: J1.98; also elsewhere on the board
I2C-0_SCL: J1.185; also elsewhere on the board
I2C-0_SDA: J1.187; also elsewhere on the board
MOD_SLEEP: J1.178; also elsewhere on the board
PCIe_CLKREQ: J1.180; also elsewhere on the board
PCIe_CLK_N: J1.160; also elsewhere on the board
PCIe_CLK_P: J1.162; also elsewhere on the board
PCIe_RX_N: J1.131; also elsewhere on the board
PCIe_RX_P: J1.133; also elsewhere on the board
PCIe_TX_N: J1.134; also elsewhere on the board
PCIe_TX_P: J1.136; also elsewhere on the board
PCIe_nRST: J1.181; also elsewhere on the board
POWER_BMC: J1.237; also elsewhere on the board
RESET_BMC: J1.239; also elsewhere on the board
SHUT_REQ_BMC: J1.233; also elsewhere on the board
SLEEP/WAKE: J1.240; also elsewhere on the board
SPI-0_CLK_1V8: J1.91; also elsewhere on the board
SPI-0_CS0_1V8: J1.95; also elsewhere on the board
SPI-0_CS1_1V8: J1.97; also elsewhere on the board
SPI-0_MISO_1V8: J1.93; also elsewhere on the board
SPI-0_MOSI_1V8: J1.89; also elsewhere on the board
SPI-1_CLK_1V8: J1.106; also elsewhere on the board
SPI-1_CS0_1V8: J1.110; also elsewhere on the board
SPI-1_CS1_1V8: J1.112; also elsewhere on the board
SPI-1_MISO_1V8: J1.108; also elsewhere on the board
SPI-1_MOSI_1V8: J1.104; also elsewhere on the board
UART-0_CTS_1V8: J1.105; also elsewhere on the board
UART-0_RTS_1V8: J1.103; also elsewhere on the board
UART-0_RX_1V8: J1.101; also elsewhere on the board
UART-0_TX_1V8: J1.99; also elsewhere on the board
UART-1_CTS_1V8: J1.209; also elsewhere on the board
UART-1_RTS_1V8: J1.207; also elsewhere on the board
UART-1_RX_1V8: J1.205; also elsewhere on the board
UART-1_TX_1V8: J1.203; also elsewhere on the board
UART-2_RX_1V8: J1.238; also elsewhere on the board
UART-2_TX_1V8: J1.236; also elsewhere on the board
USB3-0-DN: J1.109; also elsewhere on the board
USB3-0-DP: J1.111; also elsewhere on the board
USB3-0-RX_N: J1.161; also elsewhere on the board
USB3-0-RX_P: J1.163; also elsewhere on the board
USB3-0-TX_N: J1.166; also elsewhere on the board
USB3-0-TX_P: J1.168; also elsewhere on the board
USB3-1-DN: J1.115; also elsewhere on the board
USB3-1-DP: J1.117; also elsewhere on the board
USB3-1-RX_N: J1.39; also elsewhere on the board
USB3-1-RX_P: J1.41; also elsewhere on the board
USB3-1-TX_N: J1.45; also elsewhere on the board
USB3-1-TX_P: J1.47; also elsewhere on the board
VBAT: J1.235; also elsewhere on the board
dCSI-0_CLK_N: J1.10; also elsewhere on the board
dCSI-0_CLK_P: J1.12; also elsewhere on the board
dCSI-0_D0_N: J1.4; also elsewhere on the board
dCSI-0_D0_P: J1.6; also elsewhere on the board
dCSI-0_D1_N: J1.16; also elsewhere on the board
dCSI-0_D1_P: J1.18; also elsewhere on the board
dCSI-0_D2_N: J1.3; also elsewhere on the board
dCSI-0_D2_P: J1.5; also elsewhere on the board
dCSI-0_D3_N: J1.15; also elsewhere on the board
dCSI-0_D3_P: J1.17; also elsewhere on the board
dCSI-1_CLK_N: J1.28; also elsewhere on the board
dCSI-1_CLK_P: J1.30; also elsewhere on the board
dCSI-1_D0_N: J1.22; also elsewhere on the board
dCSI-1_D0_P: J1.24; also elsewhere on the board
dCSI-1_D1_N: J1.34; also elsewhere on the board
dCSI-1_D1_P: J1.36; also elsewhere on the board
dCSI-1_D2_N: J1.21; also elsewhere on the board
dCSI-1_D2_P: J1.23; also elsewhere on the board
dCSI-1_D3_N: J1.33; also elsewhere on the board
dCSI-1_D3_P: J1.35; also elsewhere on the board
dHDMI-0_CLK_N: J1.81; also elsewhere on the board
dHDMI-0_CLK_P: J1.83; also elsewhere on the board
dHDMI-0_TX0_N: J1.75; also elsewhere on the board
dHDMI-0_TX0_P: J1.77; also elsewhere on the board
dHDMI-0_TX1_N: J1.69; also elsewhere on the board
dHDMI-0_TX1_P: J1.71; also elsewhere on the board
dHDMI-0_TX2_N: J1.63; also elsewhere on the board
dHDMI-0_TX2_P: J1.65; also elsewhere on the board
dUSB_N: J1.121; also elsewhere on the board
dUSB_P: J1.123; also elsewhere on the board

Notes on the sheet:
< Research cluster board implement

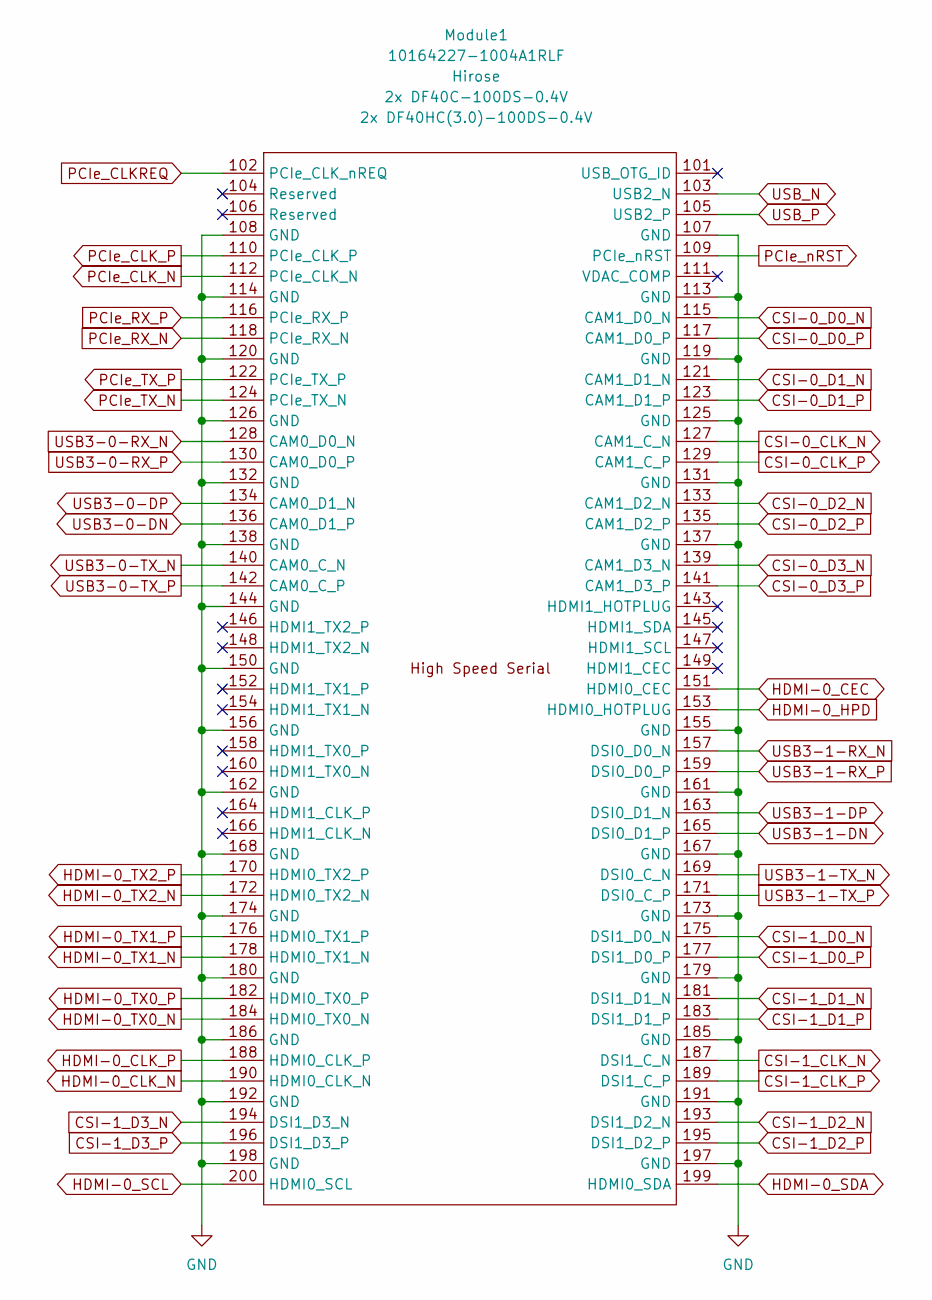
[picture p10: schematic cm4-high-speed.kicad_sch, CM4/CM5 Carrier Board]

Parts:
Module1: 10164227-1004A1RLF; Raspberry-Pi-4-Compute-Module-B; MPN 2x DF40C-100DS-0.4V; Digi-Key_PN 2x H11615CT-ND

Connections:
CSI-0_CLK_N: Module1.127 (CAM1_C_N); also elsewhere on the board
CSI-0_CLK_P: Module1.129 (CAM1_C_P); also elsewhere on the board
CSI-0_D0_N: Module1.115 (CAM1_D0_N); also elsewhere on the board
CSI-0_D0_P: Module1.117 (CAM1_D0_P); also elsewhere on the board
CSI-0_D1_N: Module1.121 (CAM1_D1_N); also elsewhere on the board
CSI-0_D1_P: Module1.123 (CAM1_D1_P); also elsewhere on the board
CSI-0_D2_N: Module1.133 (CAM1_D2_N); also elsewhere on the board
CSI-0_D2_P: Module1.135 (CAM1_D2_P); also elsewhere on the board
CSI-0_D3_N: Module1.139 (CAM1_D3_N); also elsewhere on the board
CSI-0_D3_P: Module1.141 (CAM1_D3_P); also elsewhere on the board
CSI-1_CLK_N: Module1.187 (DSI1_C_N); also elsewhere on the board
CSI-1_CLK_P: Module1.189 (DSI1_C_P); also elsewhere on the board
CSI-1_D0_N: Module1.175 (DSI1_D0_N); also elsewhere on the board
CSI-1_D0_P: Module1.177 (DSI1_D0_P); also elsewhere on the board
CSI-1_D1_N: Module1.181 (DSI1_D1_N); also elsewhere on the board
CSI-1_D1_P: Module1.183 (DSI1_D1_P); also elsewhere on the board
CSI-1_D2_N: Module1.193 (DSI1_D2_N); also elsewhere on the board
CSI-1_D2_P: Module1.195 (DSI1_D2_P); also elsewhere on the board
CSI-1_D3_N: Module1.194 (DSI1_D3_N); also elsewhere on the board
CSI-1_D3_P: Module1.196 (DSI1_D3_P); also elsewhere on the board
GND: Module1.107 (GND), Module1.108 (GND), Module1.113 (GND), Module1.114 (GND), Module1.119 (GND), Module1.120 (GND), Module1.125 (GND), Module1.126 (GND), Module1.131 (GND), Module1.132 (GND), Module1.137 (GND), Module1.138 (GND), Module1.144 (GND), Module1.150 (GND), Module1.155 (GND), Module1.156 (GND), Module1.161 (GND), Module1.162 (GND), Module1.167 (GND), Module1.168 (GND), Module1.173 (GND), Module1.174 (GND), Module1.179 (GND), Module1.180 (GND), Module1.185 (GND), Module1.186 (GND), Module1.191 (GND), Module1.192 (GND), Module1.197 (GND), Module1.198 (GND); also elsewhere on the board
HDMI-0_CEC: Module1.151 (HDMI0_CEC); also elsewhere on the board
HDMI-0_CLK_N: Module1.190 (HDMI0_CLK_N); also elsewhere on the board
HDMI-0_CLK_P: Module1.188 (HDMI0_CLK_P); also elsewhere on the board
HDMI-0_HPD: Module1.153 (HDMI0_HOTPLUG); also elsewhere on the board
HDMI-0_SCL: Module1.200 (HDMI0_SCL); also elsewhere on the board
HDMI-0_SDA: Module1.199 (HDMI0_SDA); also elsewhere on the board
HDMI-0_TX0_N: Module1.184 (HDMI0_TX0_N); also elsewhere on the board
HDMI-0_TX0_P: Module1.182 (HDMI0_TX0_P); also elsewhere on the board
HDMI-0_TX1_N: Module1.178 (HDMI0_TX1_N); also elsewhere on the board
HDMI-0_TX1_P: Module1.176 (HDMI0_TX1_P); also elsewhere on the board
HDMI-0_TX2_N: Module1.172 (HDMI0_TX2_N); also elsewhere on the board
HDMI-0_TX2_P: Module1.170 (HDMI0_TX2_P); also elsewhere on the board
PCIe_CLKREQ: Module1.102 (PCIe_CLK_nREQ); also elsewhere on the board
PCIe_CLK_N: Module1.112 (PCIe_CLK_N); also elsewhere on the board
PCIe_CLK_P: Module1.110 (PCIe_CLK_P); also elsewhere on the board
PCIe_RX_N: Module1.118 (PCIe_RX_N); also elsewhere on the board
PCIe_RX_P: Module1.116 (PCIe_RX_P); also elsewhere on the board
PCIe_TX_N: Module1.124 (PCIe_TX_N); also elsewhere on the board
PCIe_TX_P: Module1.122 (PCIe_TX_P); also elsewhere on the board
PCIe_nRST: Module1.109 (PCIe_nRST); also elsewhere on the board
USB3-0-DN: Module1.136 (CAM0_D1_P); also elsewhere on the board
USB3-0-DP: Module1.134 (CAM0_D1_N); also elsewhere on the board
USB3-0-RX_N: Module1.128 (CAM0_D0_N); also elsewhere on the board
USB3-0-RX_P: Module1.130 (CAM0_D0_P); also elsewhere on the board
USB3-0-TX_N: Module1.140 (CAM0_C_N); also elsewhere on the board
USB3-0-TX_P: Module1.142 (CAM0_C_P); also elsewhere on the board
USB3-1-DN: Module1.165 (DSI0_D1_P); also elsewhere on the board
USB3-1-DP: Module1.163 (DSI0_D1_N); also elsewhere on the board
USB3-1-RX_N: Module1.157 (DSI0_D0_N); also elsewhere on the board
USB3-1-RX_P: Module1.159 (DSI0_D0_P); also elsewhere on the board
USB3-1-TX_N: Module1.169 (DSI0_C_N); also elsewhere on the board
USB3-1-TX_P: Module1.171 (DSI0_C_P); also elsewhere on the board
USB_N: Module1.103 (USB2_N); also elsewhere on the board
USB_P: Module1.105 (USB2_P); also elsewhere on the board

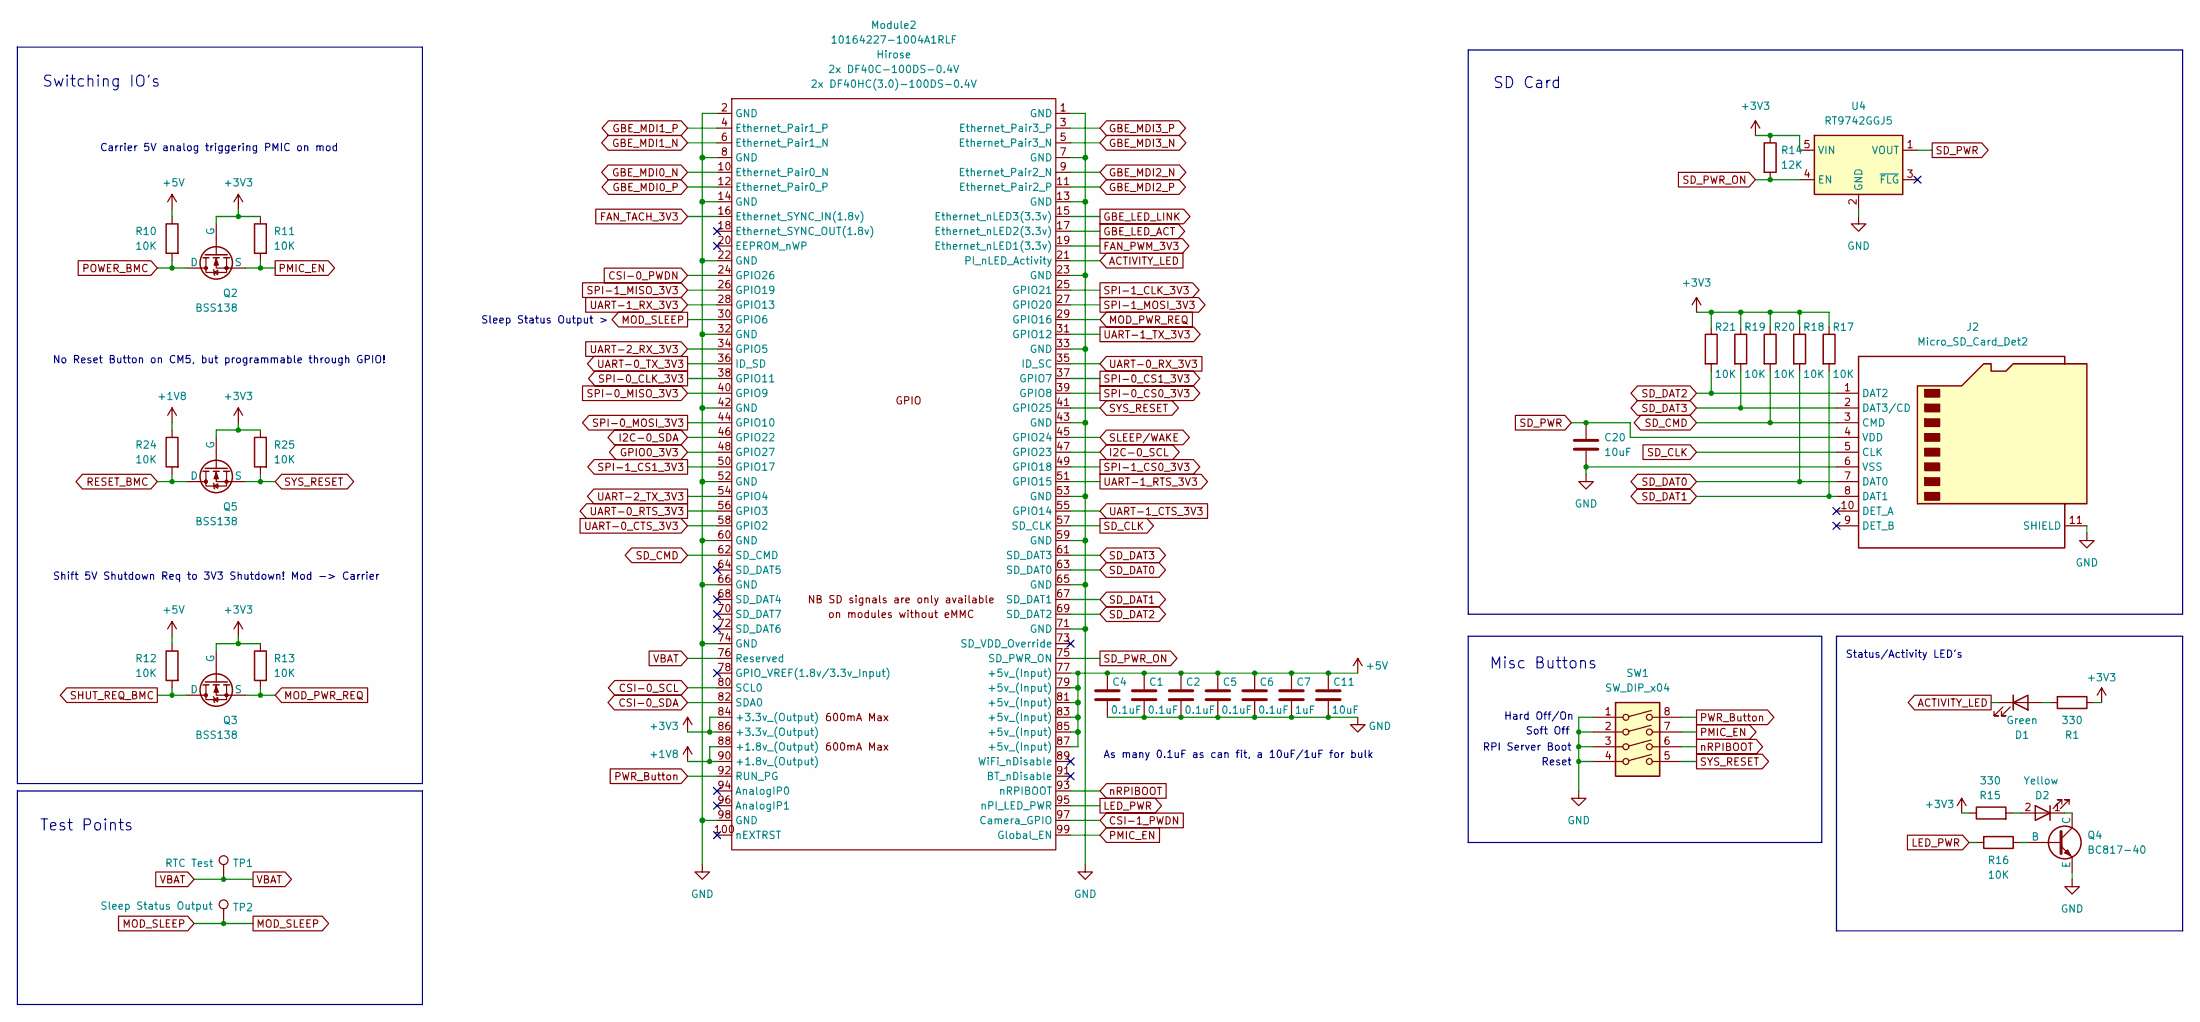
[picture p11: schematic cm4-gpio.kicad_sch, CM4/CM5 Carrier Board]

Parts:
C1, C2, C4, C5, C6: 0.1uF; C_0402_1005Metric
C7: 1uF; C_0402_1005Metric
C11, C20: 10uF; C_0603_1608Metric
D1: Green; LED_0805_2012Metric
D2: Yellow; LED_0805_2012Metric
J2: Micro_SD_Card_Det2; microSD_HC_Hirose_DM3AT-SF-PEJM5
Module2: 10164227-1004A1RLF; Raspberry-Pi-4-Compute-Module-A; MPN 2x DF40C-100DS-0.4V; Digi-Key_PN 2x H11615CT-ND
Q2, Q3, Q5: BSS138; SOT-23-3
Q4: BC817-40; SOT-323_SC-70
R1, R15: 330; R_0402_1005Metric
R10, R11, R12, R13, R16, R17, R18, R19, R20, R21, R24, R25: 10K; R_0402_1005Metric
R14: 12K; R_0402_1005Metric
SW1: SW_DIP_x04; SW_DIP_SPSTx04_Slide_Copal_CHS-04B_W7.62mm_P1.27mm
TP1: RTC Test; TestPoint_Pad_D1.0mm
TP2: Sleep Status Output; TestPoint_Pad_D1.0mm
U4: RT9742GGJ5; TSOT-23-5

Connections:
+1V8: Module2.88 (+1.8v_(Output)), Module2.90 (+1.8v_(Output)), R24.1; also elsewhere on the board
+3V3: Module2.84 (+3.3v_(Output)), Module2.86 (+3.3v_(Output)), Q2.2 (G), Q3.2 (G), Q5.2 (G), R1.1, R11.1, R13.1, R14.1, R15.1, R17.1, R18.1, R19.1, R20.1, R21.1, R25.1, U4.5 (VIN); also elsewhere on the board
+5V: C1.1, C2.1, C4.1, C5.1, C6.1, C7.1, C11.1, Module2.77 (+5v_(Input)), Module2.79 (+5v_(Input)), Module2.81 (+5v_(Input)), Module2.83 (+5v_(Input)), Module2.85 (+5v_(Input)), Module2.87 (+5v_(Input)), R10.1, R12.1; also elsewhere on the board
ACTIVITY_LED: D1.1 (K), Module2.21 (PI_nLED_Activity)
CSI-0_PWDN: Module2.24 (GPIO26); also elsewhere on the board
CSI-0_SCL: Module2.80 (SCL0); also elsewhere on the board
CSI-0_SDA: Module2.82 (SDA0); also elsewhere on the board
CSI-1_PWDN: Module2.97 (Camera_GPIO); also elsewhere on the board
FAN_PWM_3V3: Module2.19 (Ethernet_nLED1(3.3v)); also elsewhere on the board
FAN_TACH_3V3: Module2.16 (Ethernet_SYNC_IN(1.8v)); also elsewhere on the board
GBE_LED_ACT: Module2.17 (Ethernet_nLED2(3.3v)); also elsewhere on the board
GBE_LED_LINK: Module2.15 (Ethernet_nLED3(3.3v)); also elsewhere on the board
GBE_MDI0_N: Module2.10 (Ethernet_Pair0_N); also elsewhere on the board
GBE_MDI0_P: Module2.12 (Ethernet_Pair0_P); also elsewhere on the board
GBE_MDI1_N: Module2.6 (Ethernet_Pair1_N); also elsewhere on the board
GBE_MDI1_P: Module2.4 (Ethernet_Pair1_P); also elsewhere on the board
GBE_MDI2_N: Module2.9 (Ethernet_Pair2_N); also elsewhere on the board
GBE_MDI2_P: Module2.11 (Ethernet_Pair2_P); also elsewhere on the board
GBE_MDI3_N: Module2.5 (Ethernet_Pair3_N); also elsewhere on the board
GBE_MDI3_P: Module2.3 (Ethernet_Pair3_P); also elsewhere on the board
GND: C1.2, C2.2, C4.2, C5.2, C6.2, C7.2, C11.2, C20.2, J2.6 (VSS), J2.11 (SHIELD), Module2.1 (GND), Module2.2 (GND), Module2.7 (GND), Module2.8 (GND), Module2.13 (GND), Module2.14 (GND), Module2.22 (GND), Module2.23 (GND), Module2.32 (GND), Module2.33 (GND), Module2.42 (GND), Module2.43 (GND), Module2.52 (GND), Module2.53 (GND), Module2.59 (GND), Module2.60 (GND), Module2.65 (GND), Module2.66 (GND), Module2.71 (GND), Module2.74 (GND), Module2.98 (GND), Q4.3 (E), SW1.1, SW1.2, SW1.3, SW1.4, U4.2 (GND); also elsewhere on the board
GPIO0_3V3: Module2.48 (GPIO27); also elsewhere on the board
I2C-0_SCL: Module2.47 (GPIO23); also elsewhere on the board
I2C-0_SDA: Module2.46 (GPIO22); also elsewhere on the board
LED_PWR: Module2.95 (nPI_LED_PWR), R16.2
MOD_PWR_REQ: Module2.29 (GPIO16), Q3.3 (S), R13.2
MOD_SLEEP: Module2.30 (GPIO6), TP2.1; also elsewhere on the board
unnamed: D1.2 (A), R1.2
unnamed: D2.2 (A), R15.2
unnamed: D2.1 (K), Q4.1 (C)
unnamed: Q4.2 (B), R16.1
PMIC_EN: Module2.99 (Global_EN), Q2.3 (S), R11.2, SW1.7
POWER_BMC: Q2.1 (D), R10.2; also elsewhere on the board
PWR_Button: Module2.92 (RUN_PG), SW1.8
RESET_BMC: Q5.1 (D), R24.2; also elsewhere on the board
SD_CLK: J2.5 (CLK), Module2.57 (SD_CLK)
SD_CMD: J2.3 (CMD), Module2.62 (SD_CMD), R20.2
SD_DAT0: J2.7 (DAT0), Module2.63 (SD_DAT0), R18.2
SD_DAT1: J2.8 (DAT1), Module2.67 (SD_DAT1), R17.2
SD_DAT2: J2.1 (DAT2), Module2.69 (SD_DAT2), R21.2
SD_DAT3: J2.2 (DAT3/CD), Module2.61 (SD_DAT3), R19.2
SD_PWR: C20.1, J2.4 (VDD), U4.1 (VOUT)
SD_PWR_ON: Module2.75 (SD_PWR_ON), R14.2, U4.4 (EN)
SHUT_REQ_BMC: Q3.1 (D), R12.2; also elsewhere on the board
SLEEP/WAKE: Module2.45 (GPIO24); also elsewhere on the board
SPI-0_CLK_3V3: Module2.38 (GPIO11); also elsewhere on the board
SPI-0_CS0_3V3: Module2.39 (GPIO8); also elsewhere on the board
SPI-0_CS1_3V3: Module2.37 (GPIO7); also elsewhere on the board
SPI-0_MISO_3V3: Module2.40 (GPIO9); also elsewhere on the board
SPI-0_MOSI_3V3: Module2.44 (GPIO10); also elsewhere on the board
SPI-1_CLK_3V3: Module2.25 (GPIO21); also elsewhere on the board
SPI-1_CS0_3V3: Module2.49 (GPIO18); also elsewhere on the board
SPI-1_CS1_3V3: Module2.50 (GPIO17); also elsewhere on the board
SPI-1_MISO_3V3: Module2.26 (GPIO19); also elsewhere on the board
SPI-1_MOSI_3V3: Module2.27 (GPIO20); also elsewhere on the board
SYS_RESET: Module2.41 (GPIO25), Q5.3 (S), R25.2, SW1.5
UART-0_CTS_3V3: Module2.58 (GPIO2); also elsewhere on the board
UART-0_RTS_3V3: Module2.56 (GPIO3); also elsewhere on the board
UART-0_RX_3V3: Module2.35 (ID_SC); also elsewhere on the board
UART-0_TX_3V3: Module2.36 (ID_SD); also elsewhere on the board
UART-1_CTS_3V3: Module2.55 (GPIO14); also elsewhere on the board
UART-1_RTS_3V3: Module2.51 (GPIO15); also elsewhere on the board
UART-1_RX_3V3: Module2.28 (GPIO13); also elsewhere on the board
UART-1_TX_3V3: Module2.31 (GPIO12); also elsewhere on the board
UART-2_RX_3V3: Module2.34 (GPIO5); also elsewhere on the board
UART-2_TX_3V3: Module2.54 (GPIO4); also elsewhere on the board
VBAT: Module2.76 (Reserved), TP1.1; also elsewhere on the board
nRPIBOOT: Module2.93 (nRPIBOOT), SW1.6

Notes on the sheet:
Switching IO's
Status/Activity LED's
Hard Off/On
Soft Off
Shift 5V Shutdown Req to 3V3 Shutdown! Mod -> Carrier
Carrier 5V analog triggering PMIC on mod
SD Card
Test Points
Misc Buttons
As many 0.1uF as can fit, a 10uF/1uF for bulk
No Reset Button on CM5, but programmable through GPIO!
Reset
Sleep Status Output >
RPI Server Boot

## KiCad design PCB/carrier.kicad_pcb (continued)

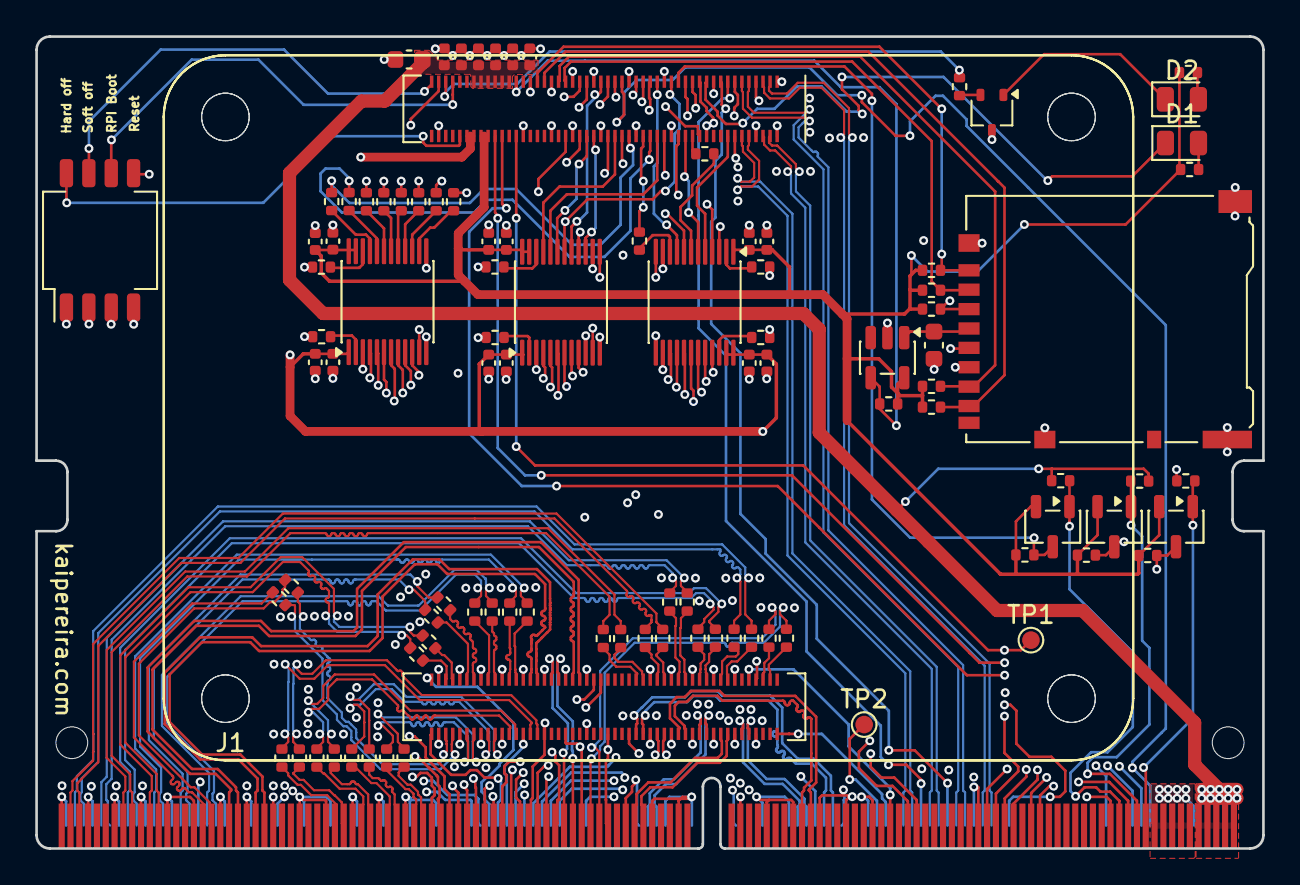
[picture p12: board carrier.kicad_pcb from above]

Board: 6 copper layers, 69.6 x 46.1 mm, 98 parts (0 on the bottom side), 191 nets.

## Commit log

2025-11-26 fixing an EMI problem!
    [carrier.kicad_pcb]
2025-11-26 updating production files
    [BOM_JLCPCB.xls, SO-DIMM.kicad_sch, SO-DIMM_pinout.csv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]

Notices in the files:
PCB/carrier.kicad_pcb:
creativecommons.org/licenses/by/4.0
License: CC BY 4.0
